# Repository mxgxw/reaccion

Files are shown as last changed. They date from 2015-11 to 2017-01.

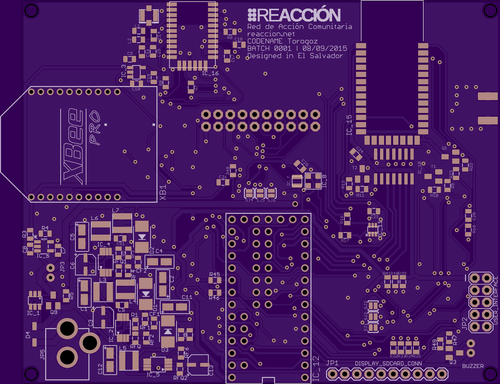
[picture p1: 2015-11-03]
dsn/main/Renders/Reaccion-00-BoardTop.png

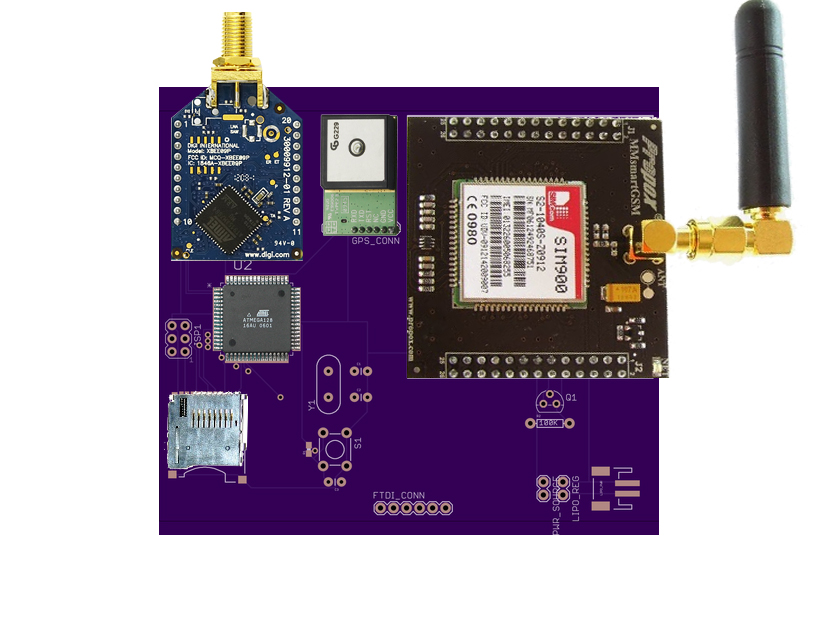
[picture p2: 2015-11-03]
extra/Graficos/Board-pre-render.jpg

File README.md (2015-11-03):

Red de Acción Comunitaria (Reaccion.net)
========================================

"Reaccion.net es una Red de Acción Comunitaria que hace uso de un
dispositivo electrónico que facilita la comunicación y coordinación
de comunidades en caso de siniestros, canalizando eficazmente la
información de alerta temprana y necesidades básicas durante
y después de una emergencia..."

El dispositivo consiste en un módulo de transmisión de datos
inalámbrico diseñado específicamente para enviar mensajes
pre-acordados en la forma de mensajes cortos tipo "semáforo"
indicando distintos niveles de alerta o impácto en una comunidad.
Los dispositivos almacenan y actualizan la información entre si al
estilo de una red P2P de tal manera que la información se guarda
de manera distribuida en toda la red.

En este proyecto de GitHub encontrarás las notas de diseño,
diagramas eléctricos, diseños de las tabletas de circuito impreso,
hojas técnicas y el sofware necesario para controlar el kit Reaccion.net.

Puedes apoyar este proyecto haciendo un "Fork" del mismo, agregando
mejoras al diseño y/o funcionamiento e incorporándolas de nuevo a
través de un "pull request".

Ayúdanos a materializar esta idea a través de SocialLab iniciado
sesión con Faceebok y haciendo click a "Vota por esta idea":

http://www.socialab.com/ideas/ver/15704

Para más información contactanos a través de nuestro
email: info _arroba_ reaccion *punto* net.

Últimas adiciones
=================

+Agregadas las hojas técnicas de los componentes bajo extra/Datasheets.

Costo/Lista de Materiales
=========================

Encuentra la lista de materiales en el archivo bom.csv

Pre-requisitos/Requerimientos
=============================

Pendiente diseño del módulo de cargador/regulador de voltaje LiPO.

Construcción y uso
==================

// TO DO

Carpetas
========

```
raíz
 |--dsn: Archivos de diseño
 |   |--main: Esquemáticos y diagrama de PCB para Eagle.
 |   |--auxiliar: Esquemático y diagrama de PCB en formato PDF imprimible.
 |--doc: Archivos de documentación para construcción y uso.
 |--src: Código fuente del software de control (Arduino).
 |--extra: Anexos
     |--Datasheets: Hojas técnicas de los componentes utilizados.
     |--Gráficos: Renders y bocetos del diseño.
     |--sketchs: Esquemas a mano rápidamente.
```

Excepción de responsabilidades
==============================

> El presente proyecto se comparte "tal cual" con el único objetivo de que sea útil.
El/los creadores del presente hardware y su software asociado no pueden garantizar su
correcto funcionamiento bajo ninguna circunstancia. El/Los autor/es de este proyecto
no podrá/n hacerse responsable/s de cualquier pérdida de carácter material, personal o
económico a su persona o terceros derivados de la utilización del mismo. Este diseño
utiliza componentes emisores de radiofrecuencia que podrían requerir algún tipo de
licenciamiento o pruebas de emisiones antes de su puesta en funcionamiento, asegurate
de estar al tanto de las regulaciones locales respecto al tema.

Licenciamiento
==============
El código fuente del software utilizado en este proyecto está protegido bajo la
licencia GNU/GPL v2.0.

Los archivos de diseño principales y auxiliares están liberados bajo la licencia
CC-BY-SA 3.0 ( https://creativecommons.org/licenses/by-sa/3.0/ ).

> La plantilla de este README.md ha sido desarrollada por la comunidad openhardware.sv
con el objetivo de facilitar la documentación de proyectos. Esta plantilla está protegida
bajo la licencia CC BY, puedes modificarla y redistribuirla manteniendo esta nota de
atribución del autor.

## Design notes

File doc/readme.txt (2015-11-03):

Carpeta de documentación
========================

Esta carpeta contiene todos los archivos de documentación para
el proyecto 72 Horas.

Archivos:

* index.html: Página principal de la documentación en formato HTML.

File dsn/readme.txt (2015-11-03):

Archivos de diseño
==================

Encuentra en esta carpeta los archivos de diagramas eléctricos para el
armado del módulo de tranmisión de datos.

Archivos de diseño principal:

* main\Enlaza.sch : Archivo fuente del diagráma eléctrico para Eagle.
* main\Enlaza.brd : Archivo fuente de la tableta impresa para Eagle.

Archivos de diseño auxiliar:
* auxiliar\Enlaza.pdf : PDF para impresión del diagrama eléctrico.

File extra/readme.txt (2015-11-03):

Archivos extra
==============

Sketchs:

Contiene todos los dibujos a mano hechos para ilustrar el funcionamiento/apariencia/diseño del proyecto.

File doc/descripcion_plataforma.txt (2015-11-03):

Introducción
============

Este documento pretende servir como una guía para explicar el
las razones detrás de la tecnología utilizada en Reacción.net.

Antes de revisar o modificar el diseño es recomendable leer
esta guía para tener una visión más clara de las limitaciones
de conectividad y uso que podría tener la plataforma en una
situación real de implementación.

El escenario
============

Al momento de ocurrir una emergencia, los redes de comunicaciones
son usualmente las primeras afectadas ya sea porque han sido
dañadas o destruidas por el evento o por saturación de las mismas
por los propios usuarios.

Para el caso de El Salvador las redes de comunicaciones de datos
usualmente solo están disponibles en las áreas más urbanizadas,
si bien existe una extensa red móvil de comunicaciones las últimas
estadísticas apuntan a casi 3 dispositivos móviles por habitante,
en una emergencia lo primero que las personas suelen hacer es
intentar comunicarse con su familia o personas cercanas saturando
la red de comunicaciones móviles.

En los últimos años las soluciones basadas en "la nube" se han
vuelto muy de moda, a pesar de tener excepcionales características
en capacidad de procesamiento y disponibilidad, para ser usables
requieren de una infraestructura de comunicaciones funcional,
haciendolas poco viables al momento de una emergencia a menos que
se invierta previamente en la creación de una infraestructura
muy resiliente a los desastres.

Diseño no intrusivo
===================

En una emergencia, la prioridad de las personas es primero velar
por su propia seguridad. Y luego, una vez esto se ha logrado, en
la medida de lo posible deberían ayudar a otras
personas que necesitan auxilio.

La primera respuesta nunca viene de un equipo especializado de
rescate, ni del gobierno, ni de un organismo internacional. La
primera respuesta es la propia gente en el lugar que ha ocurrido
un desastre dando palabras de aliento y ayudando a mantener la
calma a las personas afectadas en tanto llega la ayuda.

Por ello, cualquier diseño de un dispositivo para emergencias
debe de ser en la medida de lo posible no intrusivo permitiendo
a la gente concentrarse en la emergencia y no en el aparato.

Las vidas se salvan antes, no después
=====================================

El secreto está en la prevención, la alerta temprana y en la
organización de las comunidades. Si esto no existe se cae en
el error de ser reaccionarios y actuar luego de una catástrofe
donde ya poco o nada puede hacerse.

Mensajes cortos, simples, claros y fáciles de entender
======================================================

En emergencias, vale más un mensaje corto con un significado
bien definido que miles de mensajes con información vaga y poco
precisa. Sin embargo la combinación de ambos también puede dar
lugar a una gran cantidad de información valiosa en emergencias.

Reacción.net se centra en el primer tipo de mensajes y para ello
fundamenta su metodo de operación en los planes de emergencia
comunitarios.

Así por ejemplo, una comunidad podría acordar que "naranja"
indica en el plan de emergencia que el evento ha afectado más
de la mitad de la población.

De esta manera un "color" se vuelve un mensaje claro, previamente
acordado que acarrea una gran cantidad de información. No pretende
en ningún momento ser preciso, pero nos da una idea más clara
de la situación y es más rápido que intentar obtener un detalle
preciso luego de la emergencia.

Pensamos que el detalle es tarea de las Evaluaciones de Daños,
mientras tanto la pregunta es ¿A donde focalizar las evaluaciones?
¿Quienes podrían necesitar ayuda inmediata? ¿A donde comenzar a
intervenir? El equipo pretende ayudar a responder estas preguntas
en las primeras horas luego de ocurrido un evento.

Pérdida de la memoria
=====================

En una emergencia, uno de los problemas más graves es la pérdida
de la memoria de lo ocurrido. En un desastre de grandes proporciones
es necesario que los investigadores realizen un trabajo forense
para tratar de determinar qué fué lo que sucedio.

Reacción.net provee de un registro distribuido de eventos, de tal
manera que todos los nodos guardan información de la situación
de la red.

De esta manera aunque se perdieran todos los nodos menos uno, sería
posible regresar en el tiempo y conocer qué fué lo que ocurrió como
ocurre en las cajas negras de los aviones.

Adicionalmente el sistema está diseñado de tal manera que se pueda
sincronizar automáticamente al momento de conectarse a la red, de
tal manera que todos los nodos pueden conocer la información de los
demás.

Consideraciones técnicas
========================

Tomando en cuenta todo lo anterior, es posible definir los
parámetros de funcionamiento básico que deberá poseer el
dispositivo:

   1 - El dispositivo debe basar su funcionamiento en la interacción
       con la gente, no algo por encima de o que reemplace a la gente.
   2 - El canal de transmisión de datos no debe de ser centralizado
       y/o depender de infraestructura existente.
   3 - El canal de transmisión de datos secundario puede depender
       de infraestructura existente pero no debe de ser un requerimiento
       para el funcionamiento del dispositivo.
   4 - Cada nodo debe poseer medios para conocer su ubicación.
   5 - Cada nodo debe poseer un registro de los eventos de la red
       a la que se encuentra asociado.
   6 - La interfaz debe ser minimalista, orientada a una función 
       específica y no-intrusiva.
   7 - Infraestructura libre, replicable y adaptable por los usuarios, 
       siguiendo la filosofía del Hardware de Fuentes Abiertas.

En base a lo anterior se ha elegido la siguiente tecnología para
su funcionamiento:

1 - Basado en la gente: Si bien este no es un requerimiento técnico, el
equipo se basa en los planes de emergencia existentes, cada función del
aparto esta asociada a una acción determinada por el plan de emergencia
comunitario. No hay un mensaje "estándar" sino un mutuo acuerdo entre
las comunidades participantes y una organización previa.

2 - Canal primario:

Para proveer de conectividad  se han elegido los módulos de transmisión
de datos inalambricos de tipo espectro ensanchado XBee DIGIMESH 900HP,
estos transmisores son capaces de establecer redes malladas totalmente
descentralizadas y proveen rangos de transmisión aceptables (entre
660m y 6Km). Estos módulos se encargan de manejar todo el protocolo
de transmisión a bajo nivel permitiendo al diseñador centrarse en las
funciones de la aplicación específica más que en los detalles de la capa
de red de comunicaciones. La desventaja de estos módulos es que trabajan
con un ancho de banda muy limitado (entre 10Kbps y 200Kbps) en una banda
de transmisión de datos regulada en la mayor parte del mundo.

Partiendo de que el sistema se basa en la transmisión de datos simples,
previamente acordados el ancho de banda no debería representar mayor 
problema. Respecto al licenciamiento de los equipos creemos posible
que para el tipo de aplicación que se desea implementar se pueden obtener
las autorizaciones o licenciamientos correspondientes según
sea el caso.

3 - Canal secundario:

Se ha elegido el módulo de tranmisión de datos sobre la red GSM GPRS
PROPOX MMsmartGSM por su bajo costo y por estar basado en el chip SIM900,
este chip posee una hoja de especificaciones fácilmente accesible y
provee de la funcionalidad de "celular en un chip". Adicionalmente
cuenta con un stack TCP/IP integrado accesible desde sencillos comandos
AT vía Serial por lo que "descarga" el trabajo de establecimiento de
conexión y envio de datos al miscroprocesador principal el kit Reaccion.net.

Sin embargo, no pensamos que un canal secundario GSM GPRS sea la solución
final a todo. En futuras versiones se podría intercambiar por un módulo
WiFI o alguna solución de acceso a internét móvil como WiMAX o similares.

4 - Medios de ubicación:

Se ha elegido el módulo SkyLab SKM53, este es un módulo GSM con antena
cerámica integrada y salida de comunicaciones serial. La salida es
estándar NMEA y es de bajo muy coste.

5 - Almacenamiento:

El módulo implementa un protocolo que permite el sincronizado remoto, se
da prioridad al nodo con el mensaje más nuevo y los nodos con información
más antigua se intentan actualizar solicitando los datos al nodo con
información más reciente.

Para el almacenamiento interno se han elegido memorias del tipo SD, el
protocolo debería garantizar también la integridad de los datos y proveer
algún medio de recuperación, se espera que la estructura P2P ayude a cum
plir con este cometido.

6 - Interfaz de usuario:

Un pequeño display LCD, un buzzer de alarma sonora y un teclado de 9 teclas
compondrán la interfaz de usuario. Se utilizará un micro-controlador por
separado para administrar la interfaz de usuario y el despliegue de mensajes.

7 - Infraestructura libre y replicable:

Se ha decidido utilizar dos microcontroladores Amtel AVR por el motivo de
hacerlo compatible con la plataforma Arduino y fomentar el mejoramiento
y adaptación de la plataforma a las necesidades locales.

Los procesadores AVR son también de bajo costo, si bien su funcionalidad
puede resultar limitada, gracias a la plataforma Arduino son ampliamente
disponibles a muy bajo costo.

El sistema posee dos microcontroladores, un ATmega1280 que se encargará
de mantener los protocolos de comunicaciones. Se ha elegido este
microcontrolador por poseer 4 puertos USART por hardware, la idea de
utilizar USART es que la implementación será fácilmente adaptable que
utilizando un bus inter-chip, aunque no es una regla estricta. Es muy
posible que en futuras versiones de reaccion.net con un microcontrolador
de mayor capacidad de procesamiento sea mucho más factible utilizar un
bus de comuncación inter-chip como I2C o SPI.

El Segundo microcontrolador se encargará de manejar la interfaz de usuario,
una de las principales razones para elegir este modo de trabajo era para
"aislar" por completo los bloques funcionales, así un bug en la interfaz
de usuario no debería afectar el módulo de comunicaciones y viceversa.

Además esto permitirá mejorar la interfaz de usuario sin necesidad de
modificar el protocolo de comunicación de red.

Fuente de alimentación y consumo
================================

El sistema cuenta con un cargador/nivelador de voltaje que trabajará a
3.3V para los ATmega, el XBee y el GPS y conectará el módulo GSM
directamente a la batería del tipo Ión-Litio/Polímero.

Se espera que el sistema se encuentre en modo de escucha la mayor parte
del tiempo, esto con el objetivo de aumentar la autonomía con baterías.

Para el prototipo incial se espera que se pueda tener una autonomía
de unas 12 horas aunque se espera que para la versión final se pueda
cubrir el rango completo de las 72 horas luego de una emergencia.

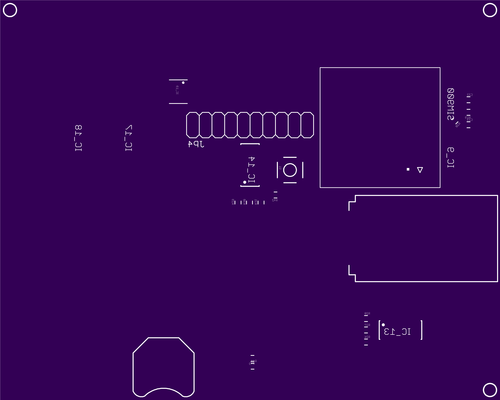
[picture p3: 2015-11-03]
dsn/main/Renders/Reaccion-04-BottomSilkScreen.png

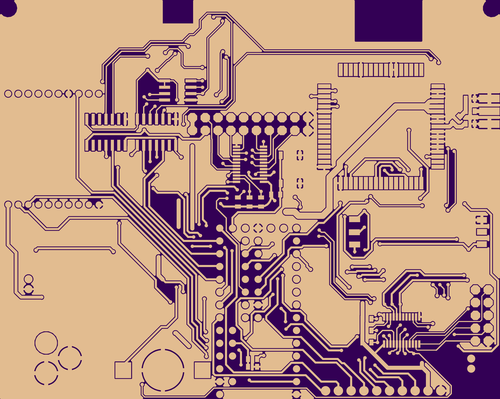
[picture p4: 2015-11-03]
dsn/main/Renders/Reaccion-04-BottomLayer.png

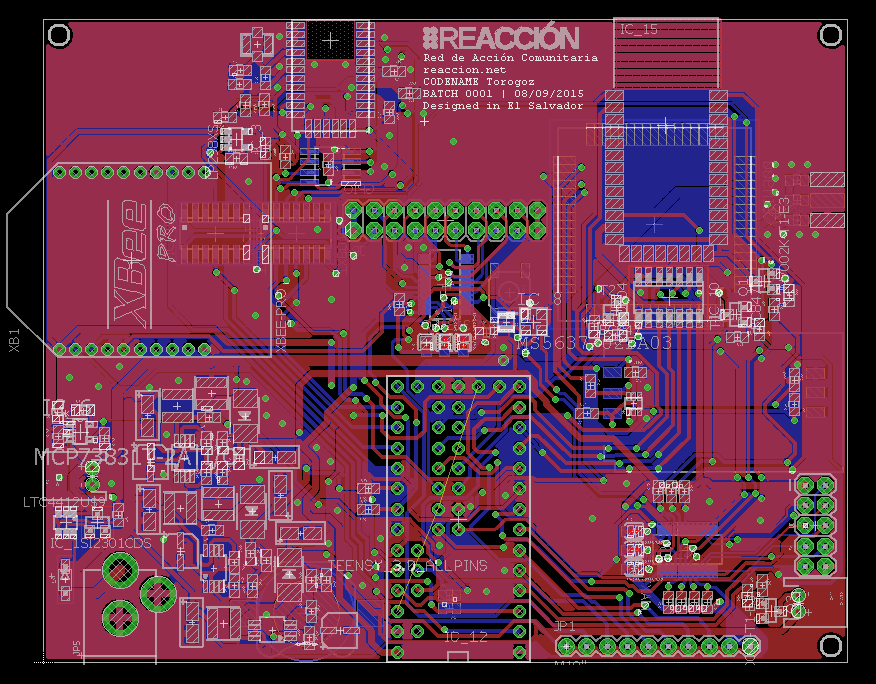
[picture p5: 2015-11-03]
dsn/main/Renders/EAGLE-PCB.png

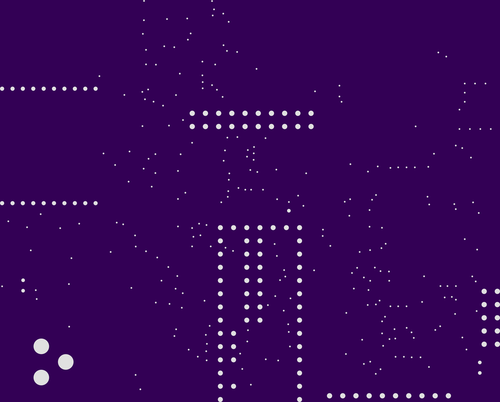
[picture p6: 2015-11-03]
dsn/main/Renders/Reaccion-02-Drills.png

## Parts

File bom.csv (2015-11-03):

# de parte del proveedor | Nombre | Descripción | Proveedor | Cantidad | Unidad medida | Precio Unitario | Total
PRT-0001 | ATmega328 with Arduino Optiboot (Uno) | Microcontrolador con bootloader pre-grabado para compatibilidad con Arduino. | SparkFun | 1 | Unidad | - | #VALOR!
MmsmartGSM | PROPOX MmsmartGSM | Módulo Módem GSM cuadribanda. | PROPOX | 1 | Unidad | - | #VALOR!
602-1349-ND | XBEE PRO S3B 900HP RPSMA | Módulo de transmisión inalambrica para redes tipo MESH. | DigiKey | 1 | Unidad | - | #VALOR!
PRT-11231 | Power Cell - LiPo Charger/Booster | Módulo para carga/nivelación de voltaje para baterías Ion Litio. | SparkFun | 1 | Unidad | - | #VALOR!
PRT-08483 | Polymer Lithium Ion Battery - 2000mAh | Batería de Ion Litio 2000mAh | SparkFun | 1 | Unidad | - | #VALOR!
COM-00538 | Crystal 8MHz | Cristal PiezoElectrico de 8MHz | SparkFun | 1 | Unidad | - | #VALOR!
COM-08571 | Capacitor Ceramic 22pF | Capacitor cerámico de 22pF | SparkFun | 2 | Unidad | - | #VALOR!
COM-08375 | Capacitor Ceramic 0.1uF | Capacitor cerámico de 0.1uF | SparkFun | 1 | Unidad | - | #VALOR!
COM-00097 | Mini Push Button Switch | Botón Pulsador | SparkFun | 1 | Unidad | - | #VALOR!

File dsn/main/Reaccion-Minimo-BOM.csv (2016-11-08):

Qty | Value | Device | Package | Parts | Description | PROD_ID | VALUE
1 |  | DIODESMB | SMB-DIODE | D1 | Diode | DIO-09646
3 |  | DIODESOD123 | SOD-123 | D2, D3, D7 | Diode
2 |  | M04PTH | 1X04 | RX_MOD_CONN, TX_MOD_CONN | Header 4
2 |  | TRANSISTOR_NPNSOT23-3 | SOT23-3 | Q1, Q2 | Generic NPN BJT | TRANS-08049
1 | 0 | RESISTOR0805-RES | 0805 | R5 | Resistor
1 | 0.1uF | CAP0805 | 0805 | C4 | Capacitor
1 | 100uF | CPOL-USB/3528-21R | T/3528-12R | C6 | POLARIZED CAPACITOR, American symbol
1 | 100uF | CPOL-USC/6032-28R | C/6032-28R | C5 | POLARIZED CAPACITOR, American symbol
1 | 10K | RESISTOR0805-RES | 0805 | R1 | Resistor
1 | 150 | RESISTOR0805-RES | 0805 | R2 | Resistor
1 | 16MHz | CRYSTAL5X3 | CRYSTAL-SMD-5X3 | Y1 | Various standard crystals. Proven footprints. | XTAL-08218
2 | 18pF | CAP0805 | 0805 | C1, C2 | Capacitor
3 | 1uF | CAP0805 | 0805 | C3, C7, C9 | Capacitor
1 | 2K2 | RESISTOR0805-RES | 0805 | R9 | Resistor
1 | 2X6 FEMALE | M06X2PTH_FEMALE | 2X6 | JP2 |  | CONN-12423 | 2X6 FEMALE
2 | 330 | RESISTOR0805-RES | 0805 | R3, R4 | Resistor
2 | 4.7K | RESISTOR0805-RES | 0805 | R6, R8 | Resistor
1 | 4.7uF | CAP0805 | 0805 | C8 | Capacitor
1 | 6K8 | RESISTOR0805-RES | 0805 | R7 | Resistor
1 | ATMEGA328P_TQFP | ATMEGA328P_TQFP | TQFP32-08 | U1 |  | IC-09069 | ATMEGA328P_TQFP
1 | AVRISP-6 | AVRISP-6 | AVRISP | ISP1 | AVR ISP HEADER
1 | BUZZERPTH | BUZZERPTH | BUZZER-12MM | SG1 | Buzzer 12mm
1 | FTDI_BASICPTH | FTDI_BASICPTH | FTDI_BASIC | JP3 | FTDI Basic header with labels
1 | LCD-HD447803-HOLES16X2-3-HOLES | LCD-HD447803-HOLES16X2-3-HOLES | LCD-16X2-3HOLES | LCD
1 | MIC5219 5V | V_REG_MIC52195V | SOT23-5 | U2 | V_REG MIC5219 | VREG-10107 | MIC5219 5V
1 | POWER_JACKPTH | POWER_JACKPTH | POWER_JACK_PTH | JP6 | Power Jack | CONN-08197
2 | RED | LED-RED1206 | LED-1206 | D5, D6 | Assorted Red LEDs | DIO-09912 | RED
5 | SWITCH-MOMENTARY-2SMD | SWITCH-MOMENTARY-2SMD | TACTILE-SWITCH-SMD | RESET, S1, S2, S3, S4 | Various NO switches- pushbuttons, reed, etc | SWCH-08247
1 | TC33 | TC33 | TC33 | U$2
1 | WS2811 | LED-TRICOLOR-5050-ICWS2811 | LED-TRICOLOR-5050-IC | U3 | WS2812 RGB LED w/ WS2811 driver | DIO-11598 | WS2811

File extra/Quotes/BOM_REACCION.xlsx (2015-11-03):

CANTIDAD | FUNCION | SUB-FUNCION | P/N | NOMBRE | COSTO | TOTAL
1 | POWER | BATT | N/D | LIPO BATT 2500mAH | $15.75 | $15.75
1 | POWER | EXTERNAL POWER | N/D | Medium 6V 2W solar panel | $47.19 | $47.19
1 | POWER | SDCARD | LM2621MM/NOPB | IC REG MULTI CONFIG ADJ 8VSSOP | $2.81 | $2.81
2 | POWER | BATT CHARGER 5V RAIL | NR4018T6R8M | FIXED IND 6.8UH 1.06A 132 MOHM | $0.48 | $0.96
1 | POWER | BATT CHARGER 5V RAIL | 08055C104KAT2A | CAP CER 0.1UF 50V 10% X7R 0805 | $0.15 | $0.15
1 | POWER | BATT CHARGER 5V RAIL | F950J336MPAAQ2 | CAP TANT 33UF 6.3V 20% 0805 | $1.41 | $1.41
1 | POWER | BATT CHARGER 5V RAIL | F921C684MPA | CAP TANT 0.68UF 16V 20% 0805 | $0.52 | $0.52
1 | POWER | BATT CHARGER 5V RAIL | C0402C330J3GACTU | CAP CER 33PF 25V 5% NP0 0402 | $0.51 | $0.51
1 | POWER | BATT CHARGER 5V RAIL | MBRS140T3G | DIODE SCHOTTKY 40V 1A SMB | $0.85 | $0.85
4 | POWER | BATT CHARGER 5V RAIL | N/D | RESISTOR 0805 | $0.15 | $0.60
1 | POWER | BATT CHARGER | MCP73811T-420I/OT | IC LI-ION/LI-POLY CTRLR SOT23-5 | $0.92 | $0.92
2 | POWER | BATT CHARGER | N/D | RESISTOR 0805 | $0.15 | $0.30
2 | POWER | BATT CHARGER | N/D | CAP CER 4.7UF X7R 0805 | $0.15 | $0.30
1 | POWER | BATT CHARGER | LTST-C191KGKT | LED GREEN CLEAR THIN 0603 SMD | $0.45 | $0.45
1 | POWER | POWERPATH CONTROLLER | LTC4412IS6#TRMPBF | IC OR CTRLR SRC SELECT TSOT23-6 | $5.15 | $5.15
1 | POWER | POWERPATH CONTROLLER | FDN306P | MOSFET P-CH 12V 2.6A SSOT3 | $0.87 | $0.87
1 | POWER | POWERPATH CONTROLLER | 1N5819HW-7-F | DIODE SCHOTTKY 40V 1A SOD123 | $0.78 | $0.78
1 | POWER | POWERPATH CONTROLLER | N/D | RESISTOR 0805 | $0.15 | $0.15
1 | POWER | 3V3 RAIL | LM2621MM/NOPB | IC REG MULTI CONFIG ADJ 8VSSOP | $2.81 | $2.81
2 | POWER | 3V3 RAIL | NR4018T6R8M | FIXED IND 6.8UH 1.06A 132 MOHM | $0.48 | $0.96
1 | POWER | 3V3 RAIL | 08055C104KAT2A | CAP CER 0.1UF 50V 10% X7R 0805 | $0.15 | $0.15
1 | POWER | 3V3 RAIL | F950J336MPAAQ2 | CAP TANT 33UF 6.3V 20% 0805 | $1.41 | $1.41
1 | POWER | 3V3 RAIL | F921C684MPA | CAP TANT 0.68UF 16V 20% 0805 | $0.52 | $0.52
1 | POWER | 3V3 RAIL | C0402C330J3GACTU | CAP CER 33PF 25V 5% NP0 0402 | $0.51 | $0.51
1 | POWER | 3V3 RAIL | MBRS140T3G | DIODE SCHOTTKY 40V 1A SMB | $0.85 | $0.85
4 | POWER | 3V3 RAIL | N/D | RESISTOR 0805 | $0.15 | $0.60
1 | POWER | 12V RAIL | LM2621MM/NOPB | IC REG MULTI CONFIG ADJ 8VSSOP | $2.81 | $2.81
1 | POWER | 12V RAIL | NR4018T6R8M | FIXED IND 6.8UH 1.06A 132 MOHM | $0.48 | $0.48
1 | POWER | 12V RAIL | F950J336MPAAQ2 | CAP TANT 33UF 6.3V 20% 0805 | $1.41 | $1.41
1 | POWER | 12V RAIL | F921C684MPA | CAP TANT 0.68UF 16V 20% 0805 | $0.52 | $0.52
1 | POWER | 12V RAIL | C0402C330J3GACTU | CAP CER 33PF 25V 5% NP0 0402 | $0.51 | $0.51
1 | POWER | 12V RAIL | MBRS140T3G | DIODE SCHOTTKY 40V 1A SMB | $0.85 | $0.85
4 | POWER | 12V RAIL | N/D | RESISTOR 0805 | $0.15 | $0.60
1 | POWER | 1V8 RAIL | TC1015-1.8VCT713 | IC REG LDO 1.8V 0.1A SOT23-5 | $0.61 | $0.61
1 | POWER | 1V8 RAIL | N/D | CAPACITOR GEN | $0.75 | $0.75
1 | DEVICES | GPS | M10478-A1 | GPS ANTENNOVA | $29.28 | $29.28
6 | DEVICES | GPS | N/D | CAPACITOR GEN | $0.75 | $4.50
3 | DEVICES | GPS | N/D | RESISTOR 0805 | $0.15 | $0.45
1 | DEVICES | GPS | SST25WF040B-40I/SN | IC FLASH 4MB 40MHZ SPI 8SOIC | $1.42 | $1.42
1 | DEVICES | GPS | TXB0104D | IC VOLT-LEVEL TRANSLATOR 14-SOIC | $2.62 | $2.62
1 | DEVICES | GSM/GPRS | SIM900 | QUAD BAND GSM/GPRS MODEM | $21.75 | $21.75
3 | DEVICES | GSM/GPRS | BC847 | TRANSISTOR/GENERIC | $0.32 | $0.95
10 | DEVICES | GSM/GPRS | N/D | RESISTOR 0805 | $0.15 | $1.50
3 | DEVICES | GSM/GPRS | N/D | CAPACITOR GEN | $0.75 | $2.25
1 | DEVICES | GSM/GPRS | SMF05C.TCT | TVS DIODE 5VWM 12.5VC SC70-6 | $1.26 | $1.26
1 | DEVICES | GSM/GPRS | 9162006301150 | CONN SIM CARD HINGED TYPE R/A | $1.97 | $1.97
1 | DEVICES | GSM/GPRS | TXB0104D | IC VOLT-LEVEL TRANSLATOR 14-SOIC | $2.62 | $2.62
1 | DEVICES | DISPLAY | PID-1480 | 2.2'' DISPLAY | $26.25 | $26.25
1 | DEVICES | SDCARD | DM3CS-SF | CONN MICRO SD CARD HINGED TYPE | $2.49 | $2.49
2 | DEVICES | SDCARD | SMF05C.TCT | TVS DIODE 5VWM 12.5VC SC70-6 | $1.26 | $2.52
1 | DEVICES | XBEE | XBP9B-DMST-012 | XBEE PRO DIGMESH S3B 900HP RPSMA | $58.50 | $58.50
1 | DEVICES | XBEE | 0600-00028 | ANTENNA 915MHZ 1/2WV 6" RA RPSMA | $21.00 | $21.00
1 | DEVICES | UI | SMF05C.TCT | TVS DIODE 5VWM 12.5VC SC70-6 | $1.26 | $1.26
4 | DEVICES | UI | N/D | WATERPROOF METAL BUTTON | $5.25 | $21.00
1 | DEVICES | UI | N/D | ANALOG THUMB JOYSTICK | $3.68 | $3.68
1 | DEVICES | UI | MAS800SQ | BUZ PIEZO 12V CIRC 26.3MM RADIAL | $11.01 | $11.01
1 | CORE | CORE | MK60FN1M0VLQ12 | IC MCU ARM 1MB FLASH 144LQFP | $20.05 | $20.05
1 | CORE | USB | 10118194-0001LF | Connector Receptacle USB - micro B 2.0 5 Position Surface Mount, Right Angle, Horizontal | $0.69 | $0.69
1 | DEVICES | GSM/GPRS | N/D | CAPACITOR GEN | $0.75 | $0.75
1 | MANUF | MANUF | N/D | EXPRESS PCB FAB | $11.38 | $11.38
1 | MANUF | MANUF | N/D | ASSEMBLY | $99.75 | $99.75
GRAN TOTAL |  |  |  |  |  | $446.94

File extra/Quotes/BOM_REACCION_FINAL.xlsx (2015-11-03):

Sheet: KIT REACCION
CANTIDAD | FUNCION | SUB-FUNCION | P/N | NOMBRE
1 | POWER | BATT | N/D | LIPO BATT 2500mAH
1 | POWER | EXTERNAL POWER | N/D | Medium 6V 2W solar panel
1 | POWER | BATT CHARGER 5V RAIL | LM2621MM/NOPB | IC REG MULTI CONFIG ADJ 8VSSOP
2 | POWER | BATT CHARGER 5V RAIL | NR4018T6R8M | FIXED IND 6.8UH 1.06A 132 MOHM
1 | POWER | BATT CHARGER 5V RAIL | 08055C104KAT2A | CAP CER 0.1UF 50V 10% X7R 0805
1 | POWER | BATT CHARGER 5V RAIL | F950J336MPAAQ2 | CAP TANT 33UF 6.3V 20% 0805
1 | POWER | BATT CHARGER 5V RAIL | F921C684MPA | CAP TANT 0.68UF 16V 20% 0805
1 | POWER | BATT CHARGER 5V RAIL | C0402C330J3GACTU | CAP CER 33PF 25V 5% NP0 0402
1 | POWER | BATT CHARGER 5V RAIL | MBRS140T3G | DIODE SCHOTTKY 40V 1A SMB
4 | POWER | BATT CHARGER 5V RAIL | N/D | RESISTOR 0805
1 | POWER | BATT CHARGER | MCP73811T-420I/OT | IC LI-ION/LI-POLY CTRLR SOT23-5
2 | POWER | BATT CHARGER | N/D | RESISTOR 0805
2 | POWER | BATT CHARGER | N/D | CAP CER 4.7UF X7R 0805
1 | POWER | BATT CHARGER | LTST-C191KGKT | LED GREEN CLEAR THIN 0603 SMD
1 | POWER | POWERPATH CONTROLLER | LTC4412IS6#TRMPBF | IC OR CTRLR SRC SELECT TSOT23-6
1 | POWER | POWERPATH CONTROLLER | FDN306P | MOSFET P-CH 12V 2.6A SSOT3
1 | POWER | POWERPATH CONTROLLER | 1N5819HW-7-F | DIODE SCHOTTKY 40V 1A SOD123
1 | POWER | POWERPATH CONTROLLER | N/D | RESISTOR 0805
1 | POWER | 3V3 RAIL | LM2621MM/NOPB | IC REG MULTI CONFIG ADJ 8VSSOP
2 | POWER | 3V3 RAIL | NR4018T6R8M | FIXED IND 6.8UH 1.06A 132 MOHM
1 | POWER | 3V3 RAIL | 08055C104KAT2A | CAP CER 0.1UF 50V 10% X7R 0805
1 | POWER | 3V3 RAIL | F950J336MPAAQ2 | CAP TANT 33UF 6.3V 20% 0805
1 | POWER | 3V3 RAIL | F921C684MPA | CAP TANT 0.68UF 16V 20% 0805
1 | POWER | 3V3 RAIL | C0402C330J3GACTU | CAP CER 33PF 25V 5% NP0 0402
1 | POWER | 3V3 RAIL | MBRS140T3G | DIODE SCHOTTKY 40V 1A SMB
4 | POWER | 3V3 RAIL | N/D | RESISTOR 0805
1 | POWER | 12V RAIL | LM2621MM/NOPB | IC REG MULTI CONFIG ADJ 8VSSOP
1 | POWER | 12V RAIL | NR4018T6R8M | FIXED IND 6.8UH 1.06A 132 MOHM
1 | POWER | 12V RAIL | F950J336MPAAQ2 | CAP TANT 33UF 6.3V 20% 0805
1 | POWER | 12V RAIL | F921C684MPA | CAP TANT 0.68UF 16V 20% 0805
1 | POWER | 12V RAIL | C0402C330J3GACTU | CAP CER 33PF 25V 5% NP0 0402
1 | POWER | 12V RAIL | MBRS140T3G | DIODE SCHOTTKY 40V 1A SMB
4 | POWER | 12V RAIL | N/D | RESISTOR 0805
1 | POWER | 1V8 RAIL | TC1015-1.8VCT713 | IC REG LDO 1.8V 0.1A SOT23-5
1 | POWER | 1V8 RAIL | N/D | CAPACITOR GEN
1 | DEVICES | GPS | M10478-A1 | GPS ANTENNOVA
6 | DEVICES | GPS | N/D | CAPACITOR GEN
3 | DEVICES | GPS | N/D | RESISTOR 0805
1 | DEVICES | GPS | SST25WF040B-40I/SN | IC FLASH 4MB 40MHZ SPI 8SOIC
1 | DEVICES | GPS | TXB0104D | IC VOLT-LEVEL TRANSLATOR 14-SOIC
1 | DEVICES | GSM/GPRS | SIM900 | QUAD BAND GSM/GPRS MODEM
3 | DEVICES | GSM/GPRS | BC847 | TRANSISTOR/GENERIC
10 | DEVICES | GSM/GPRS | N/D | RESISTOR 0805
3 | DEVICES | GSM/GPRS | N/D | CAPACITOR GEN
1 | DEVICES | GSM/GPRS | SMF05C.TCT | TVS DIODE 5VWM 12.5VC SC70-6
1 | DEVICES | GSM/GPRS | 9162006301150 | CONN SIM CARD HINGED TYPE R/A
1 | DEVICES | GSM/GPRS | TXB0104D | IC VOLT-LEVEL TRANSLATOR 14-SOIC
1 | DEVICES | DISPLAY | PID-1480 | 2.2'' DISPLAY
1 | DEVICES | SDCARD | DM3CS-SF | CONN MICRO SD CARD HINGED TYPE
2 | DEVICES | SDCARD | SMF05C.TCT | TVS DIODE 5VWM 12.5VC SC70-6
1 | DEVICES | XBEE | XBP9B-DMST-012 | XBEE PRO DIGMESH S3B 900HP RPSMA
1 | DEVICES | XBEE | 0600-00028 | ANTENNA 915MHZ 1/2WV 6" RA RPSMA
1 | DEVICES | UI | SMF05C.TCT | TVS DIODE 5VWM 12.5VC SC70-6
4 | DEVICES | UI | N/D | WATERPROOF METAL BUTTON
1 | DEVICES | UI | N/D | ANALOG THUMB JOYSTICK
1 | DEVICES | UI | MAS800SQ | BUZ PIEZO 12V CIRC 26.3MM RADIAL
1 | CORE | CORE | MK60FN1M0VLQ12 | IC MCU ARM 1MB FLASH 144LQFP
1 | CORE | USB | 10118194-0001LF | Connector Receptacle USB - micro B 2.0 5 Position Surface Mount, Right Angle, Horizontal
1 | DEVICES | GSM/GPRS | N/D | CAPACITOR GEN
1 | MANUF | MANUF | N/D | EXPRESS PCB FAB
1 | MANUF | MANUF | N/D | ASSEMBLY

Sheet: KIT VISOR
CANTIDAD | FUNCION | SUB-FUNCION | NOMBRE
1 | VISOR | VISOR | RASPBERRY PI 2 - MODEL B
1 | VISOR | XBEE | XBEE 900HP
1 | VISOR | XBEE | ANTENNA
1 | VISOR | XBEE BREAKOUT | XBEE BASE
1 | VISOR | VISOR | CASE RASPBERRY PI 2
1 | VISOR | VISOR | FUENTE RASPBERRY PI
1 | VISOR | VISOR | CABLE HDMI
1 | VISOR | VISOR | XBEE 900HP

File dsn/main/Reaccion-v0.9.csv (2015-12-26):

Part | Value | Device | Package | Description | MF | MPN | OC_FARNELL | OC_NEWARK | PACKAGE | PROD_ID | SUPPLIER | VALUE
BAT1 | 3.7V | BATTERY12MM | BATTCON_12MM | Battery Holders |  |  |  |  |  | BATT-08044
BUZZER | BATT | M02-JST-2-PTH-NO_SILK | JST-2-PTH-NS | Standard 2-pin 0.1 header. Use with"
C1 | 0.22uF | CAP0805 | 0805 | Capacitor
C2 | 68pF | CAP0805 | 0805 | Capacitor
C3 | 22uF | CAP0805 | 0805 | Capacitor
C4 | 0.22uF | CAP0805 | 0805 | Capacitor
C5 | 68pF | CAP0805 | 0805 | Capacitor
C6 | 47uF | CAP0805 | 0805 | Capacitor
C7 | 4.7uF | CAP0805 | 0805 | Capacitor
C8 | 4.7uF | CAP0805 | 0805 | Capacitor
C9 | 2.2uF | CAP0805 | 0805 | Capacitor
C10 | 470pF | CAP0805 | 0805 | Capacitor
C11 | 470pF | CAP0805 | 0805 | Capacitor
C14 |  | CAP0805 | 0805 | Capacitor
C15 | 2.2uF | CAP0805 | 0805 | Capacitor
C16 | 2.2uF | CAP0805 | 0805 | Capacitor
C17 | 22pF | CAP0805 | 0805 | Capacitor
C18 | 22pF | CAP0805 | 0805 | Capacitor
C19 | 22pF | CAP0805 | 0805 | Capacitor
C20 | 22pF | CAP0805 | 0805 | Capacitor
C21 | 100nF | CAP0805 | 0805 | Capacitor
C22 |  | CAP0805 | 0805 | Capacitor
C23 |  | CAP0805 | 0805 | Capacitor
C24 | 1uF | CAP0805 | 0805 | Capacitor
C25 | 1uF | CAP0805 | 0805 | Capacitor
C27 | 1uF | CAP0805 | 0805 | Capacitor
C28 | 1uF | CAP0805 | 0805 | Capacitor
CIN | 100uF | TPSB107M010R0400 | 1210-POLARIZED
CIN1 | 100uF | TPSB107M010R0400 | 1210-POLARIZED
D4 | 1N5819HW-7-F | 1N5819HW-7-F | SOD123
DOUT | SD1206S040S2R0 | SD1206S040S2R0 | 1206-POL
DOUT1 | SD1206S040S2R0 | SD1206S040S2R0 | 1206-POL
IC_1 | LTC4412 | LTC4412 | SOT23-6L
IC_3 | LP298XS | LP298XS | SOT23-5L
IC_6 | MCP73831T-2ATI/OT | MCP73831T-2ATI/OT | SOT95P300X145-5N | IC, BATT CHARGER, Li-Ion Li-Polymer, 500 mA |  | MCP73831T-2ATI/OT | 1834890 | 84R5196 | SOT23-5 |  | Microchip
IC_7 | MMA8653FC | MMA8653FC | 2X2-DFN
IC_8 | MS5637-02BA03 | MS5637-02BA03 | MS5637-02BA03
IC_9 | SIM900 | SIM900 | SIM900
IC_10 | TXB0104 | TXB0104 | SO14
IC_11 | SMF05C | SMF05C | SOT665
IC_12 | TEENSY_3.0_ALLPINS | TEENSY_3.0_ALLPINS | TEENSY_3.0_ALLPINS | Teensy 3.0 with all pin holes and optional SMD-mount unshrouded header on bottom of Teensy 3.0. For more basic versions, see 'Basic', '+4' and 'AllAnalogPins'.Requires the installation of a un-shrouded SMD header on the underside of the Teensy 3.0
IC_13 | MAX7313AEG | MAX7313AEG | QSOP24 | 16-Port I/O Expander with LED Intensity Control, Interrupt, and Hot-Insertion Protection |  | MAX7313AEG+ | unknown | 53K7268
IC_15 | HC_05 | HC_05 | BLUETOOTH_SMD | HC-05 Bluetooth Module
IC_16 | M10478 | M10478 | M10478
IC_17 | TXB0104 | TXB0104 | SO14
IC_18 | TXB0104 | TXB0104 | SO14
IC_19 | SST25WF040B | SST25WF040B | SO08
J$1 | SMA_EDGE | SMA_EDGE | SMA-EDGE | SMA Antenna Connector
J1 | U.FL | U.FL | U.FL | SMD antenna connector- WRL-09144
JP1 | M10";M10"" | 1X10 | Header 10
JP2 | UI | PINHD-2X5 | 2X05 | PIN HEADER
JP3 | BATT | M02-JST-2-PTH-NO_SILK | JST-2-PTH-NS | Standard 2-pin 0.1 header. Use with"
JP6 | USB-B | USBPTH | USB-B-PTH | USB Connectors |  |  |  |  |  | CONN-08278 |  | USB-B
L1 |  | INDUCTOR0805 | 0805 | Inductors
L2 |  | INDUCTOR0805 | 0805 | Inductors
L3 | 1.8uH | SRR4028 | SRR4028 | POWER INDUCTOR
L6 | 1.8uH | SRR4028 | SRR4028 | POWER INDUCTOR
Q1 | 2N7002K-T1-E3 | MOSFET-NREFLOW | SOT23 | N-Channel Mosfet
Q3 | 2N7002K-T1-E3 | MOSFET-NREFLOW | SOT23 | N-Channel Mosfet
Q9 | SI2301CDS | SI2301CDS | SOT23
R1 | 10K | RESISTOR0805-RES | 0805 | Resistor
R2 | 10K | RESISTOR0805-RES | 0805 | Resistor
R3 | 10k | RESISTOR0805-RES | 0805 | Resistor
R4 | 2K | RESISTOR0805-RES | 0805 | Resistor
R5 | 10k | RESISTOR0805-RES | 0805 | Resistor
R6 | 10K | RESISTOR0805-RES | 0805 | Resistor
R7 | 10K | RESISTOR0805-RES | 0805 | Resistor
R8 | 10K | RESISTOR0805-RES | 0805 | Resistor
R9 | 10K | RESISTOR0805-RES | 0805 | Resistor
R10 | 10K | RESISTOR0805-RES | 0805 | Resistor
R11 | 10K | RESISTOR0805-RES | 0805 | Resistor
R12 | 10K | RESISTOR0805-RES | 0805 | Resistor
R13 | 30K | RESISTOR0805-RES | 0805 | Resistor
R14 | 10K | RESISTOR0805-RES | 0805 | Resistor
R15 | 84.5K | RESISTOR0805-RES | 0805 | Resistor
R16 | 22 | RESISTOR0805-RES | 0805 | Resistor
R17 | 22 | RESISTOR0805-RES | 0805 | Resistor
R18 | 22 | RESISTOR0805-RES | 0805 | Resistor
R19 | 0 | RESISTOR0805-RES | 0805 | Resistor
R20 | 0 | RESISTOR0805-RES | 0805 | Resistor
R21 | 10K | RESISTOR0805-RES | 0805 | Resistor
R22 | 10K | RESISTOR0805-RES | 0805 | Resistor
R23 | 10K | RESISTOR0805-RES | 0805 | Resistor
R26 | 4.7K | RESISTOR0805-RES | 0805 | Resistor
R27 | 4.7K | RESISTOR0805-RES | 0805 | Resistor
R28 | 4.7K | RESISTOR0805-RES | 0805 | Resistor
R42 | 4.7K | RESISTOR0805-RES | 0805 | Resistor
R43 | 10K | RESISTOR0805-RES | 0805 | Resistor
R44 | 10K | RESISTOR0805-RES | 0805 | Resistor
R45 | 4.7K | RESISTOR0805-RES | 0805 | Resistor
R46 | 4.7K | RESISTOR0805-RES | 0805 | Resistor
R47 | 10K | RESISTOR0805-RES | 0805 | Resistor
R49 | 10K | RESISTOR0805-RES | 0805 | Resistor
S1 | SWITCH-MOMENTARY-2SMD-REDUNDANT | SWITCH-MOMENTARY-2SMD-REDUNDANT | TACTILE-SWITCH-SMD | Various NO switches- pushbuttons, reed, etc |  |  |  |  |  | SWCH-08247
SIMCONN | SIMHOLDER3 | SIMHOLDER3 | SIMHOLDER3 | Alternate SIM card socket
SJ1 | SOLDERJUMPERTRACE | SOLDERJUMPERTRACE | SJ_2S-TRACE | Solder Jumper
SJ2 | SOLDERJUMPERTRACE | SOLDERJUMPERTRACE | SJ_2S-TRACE | Solder Jumper
SJ3 | SOLDERJUMPERTRACE | SOLDERJUMPERTRACE | SJ_2S-TRACE | Solder Jumper
T1 | BC847 | BC847 | SOT23 | NPN TRANSISTOR
T2 | BC847 | BC847 | SOT23 | NPN TRANSISTOR
U$1 | LT1935ES5 | LT1935ES5 | SOT23-5
U$2 | LT1935ES5 | LT1935ES5 | SOT23-5
U1 | MIC5219 3.3V | V_REG_MIC52193.3V | SOT23-5 | V_REG MIC5219 |  |  |  |  |  | VREG-09872 |  | MIC5219 3.3V
XB1 | XBEE-PRO | XBEE-PRO | XBEE-PRO | XBee (TM) /XBee-PRO(TM) OEM RF Modules |  | XBP24-AWI-001 | 1337916 | 42M2667

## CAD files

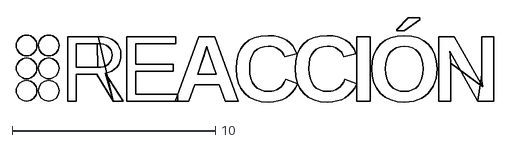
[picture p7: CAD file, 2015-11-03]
extra/Graficos/logo_PCB.dxf
23.5 x 4.14

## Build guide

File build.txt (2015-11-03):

Construyendo mi proyecto
========================

TODO.

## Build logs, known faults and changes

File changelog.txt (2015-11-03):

Versión 0.01
===========================
Publicada: 12/01/14

Cambios:

* Agregados esquematicos e ingresada plantilla OSHW

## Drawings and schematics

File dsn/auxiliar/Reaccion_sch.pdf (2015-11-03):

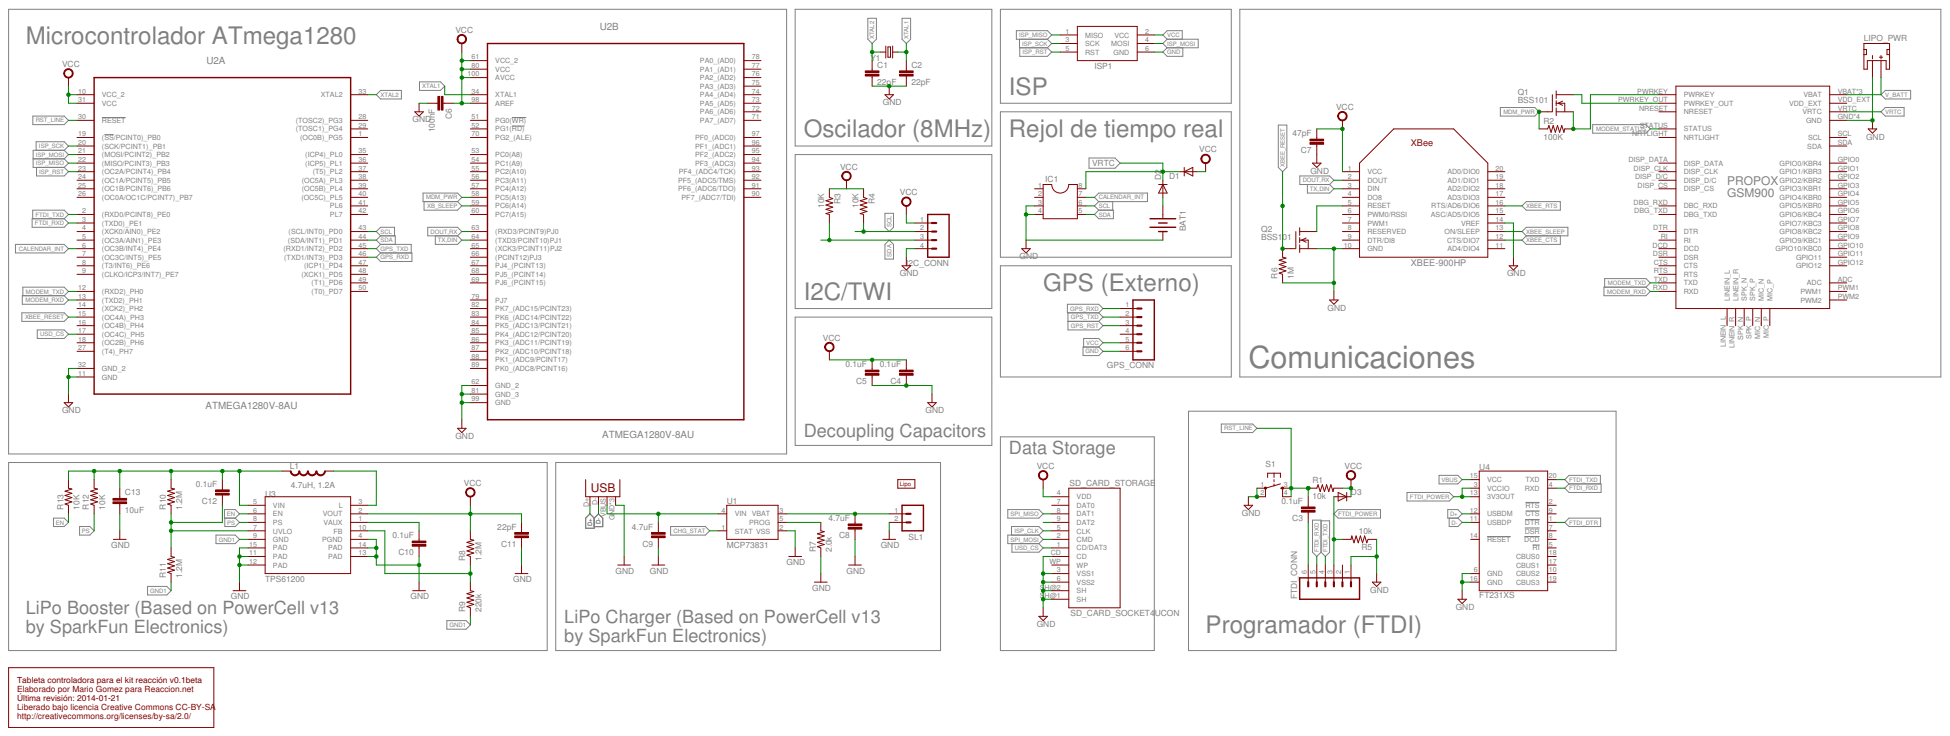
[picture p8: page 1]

LiPo Booster (Based on PowerCell v13
by SparkFun Electronics)

LiPo Charger (Based on PowerCell v13

Tableta controladora para el kit reacción v0.1beta
Elaborado por Mario Gomez para Reaccion.net Última revisión: 2014-01-21

Liberado bajo licencia Creative Commons CC-BY-SA
http://creativecommons.org/licenses/by-sa/2.0/

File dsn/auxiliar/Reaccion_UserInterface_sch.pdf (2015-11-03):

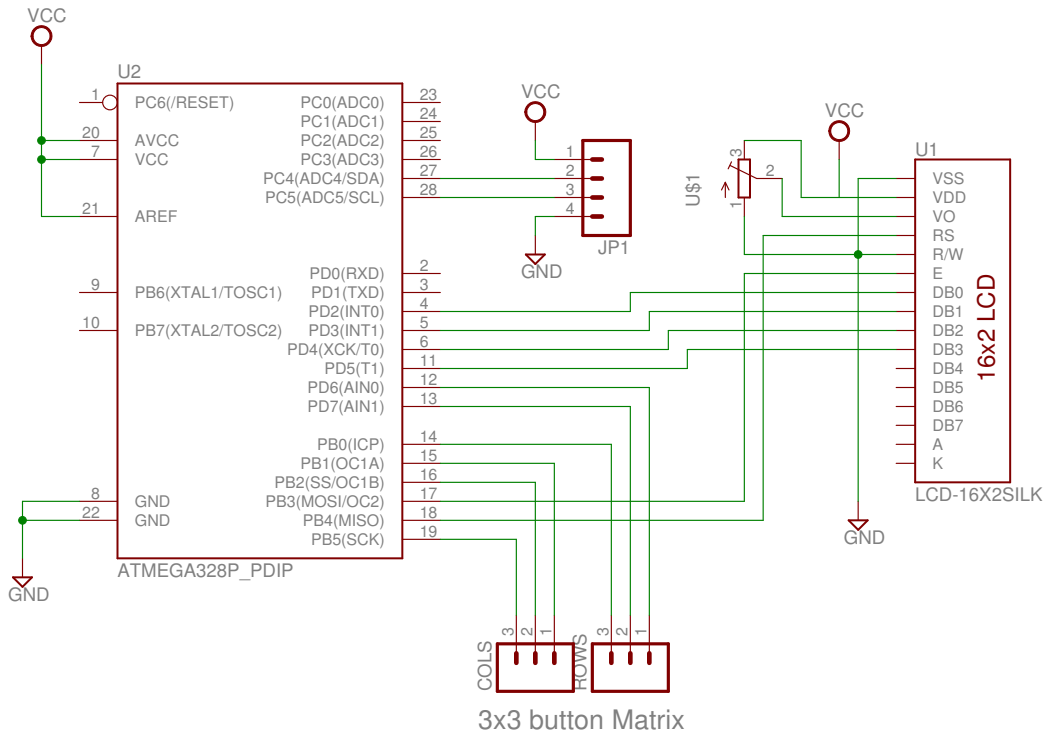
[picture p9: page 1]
3x3 button Matrix; LCD-16X2SILK; ATMEGA328P_PDIP; VCC; GND; VDD VO; VSS; PB5(SCK); PB7(XTAL2/TOSC2) 10; PB6(XTAL1/TOSC1); 8 GND 22; AREF 21; AVCC 20; PB4(MISO); 18 PB3(MOSI/OC2); 15 PB0(ICP); PD7(AIN1); 13 PD6(AIN0); 11 PD4(XCK/T0); 6 PD3(INT1); 5 PD2(INT0); 4 PD1(TXD); 3 PD0(RXD); PC5(ADC5/SCL); 28 PC4(ADC4/SDA); 27 PC3(ADC3); 26 PC2(ADC2); 25 PC1(ADC1); 24 PC0(ADC0); 23 PC6(/RESET); COLS; ROWS; 16x2 LCD

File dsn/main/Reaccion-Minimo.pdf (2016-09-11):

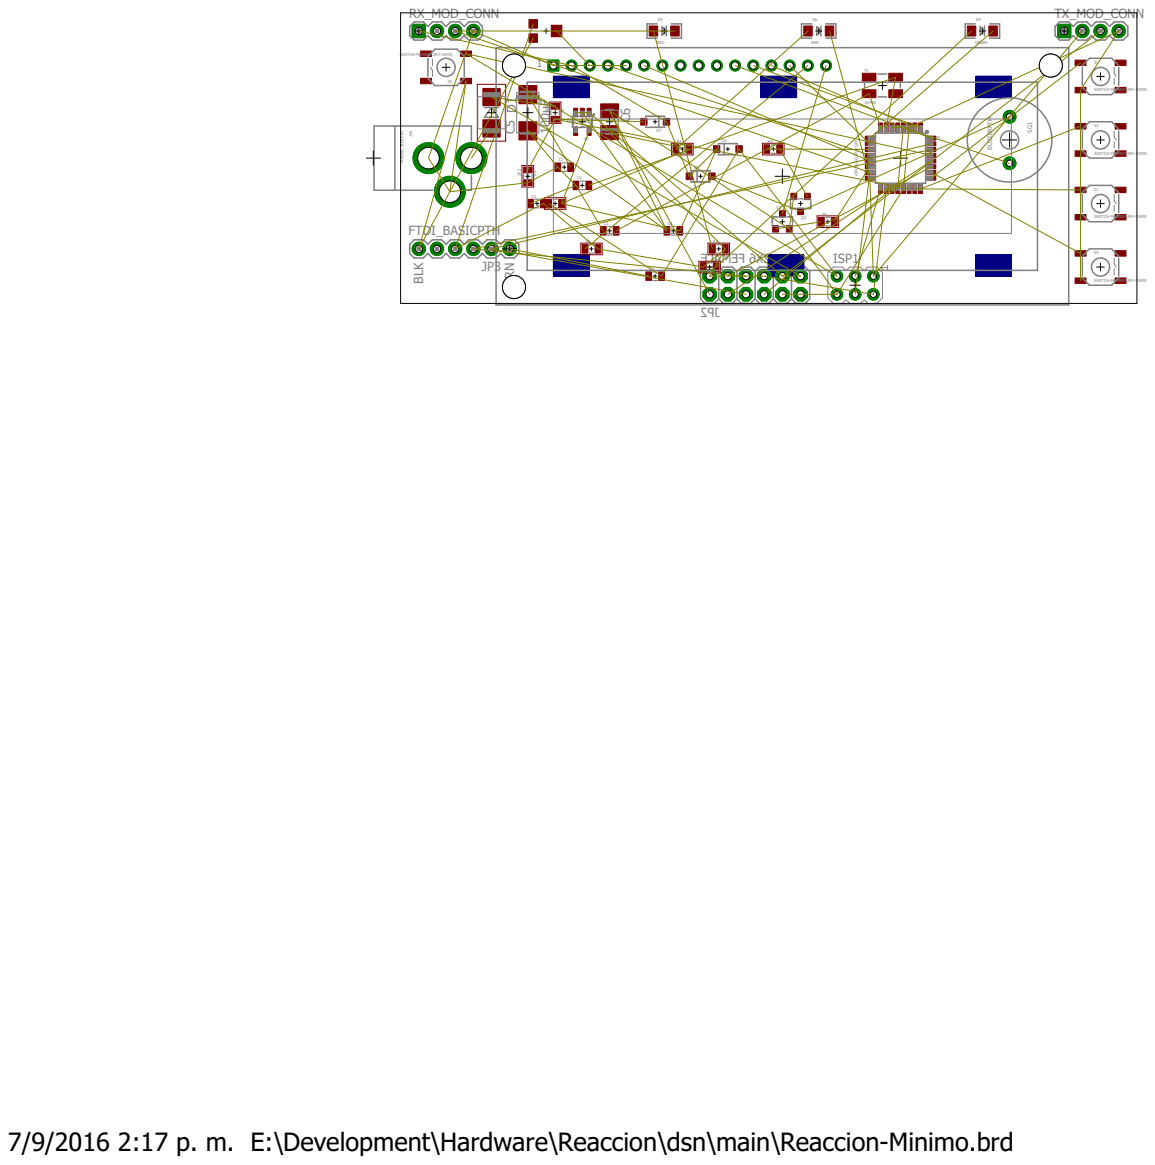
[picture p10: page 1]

7/9/2016 2:17 p. m. E:\Development\Hardware\Reaccion\dsn\main\Reaccion-Minimo.brd

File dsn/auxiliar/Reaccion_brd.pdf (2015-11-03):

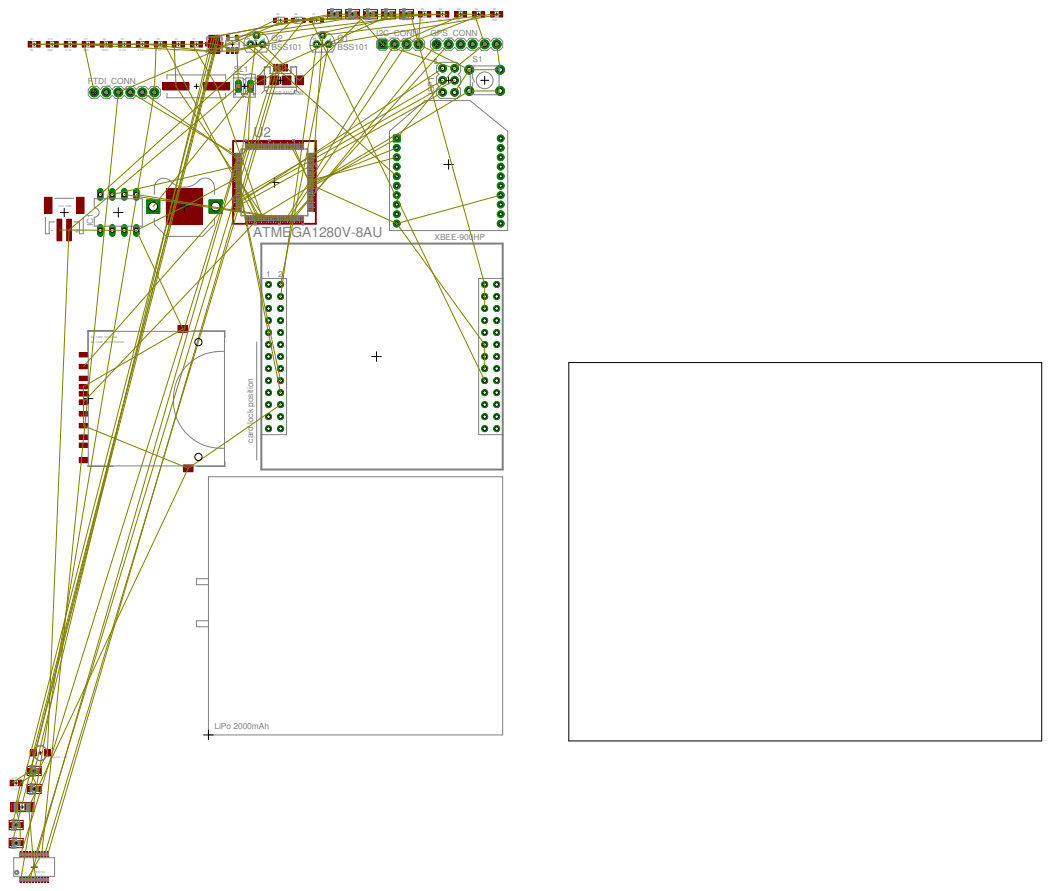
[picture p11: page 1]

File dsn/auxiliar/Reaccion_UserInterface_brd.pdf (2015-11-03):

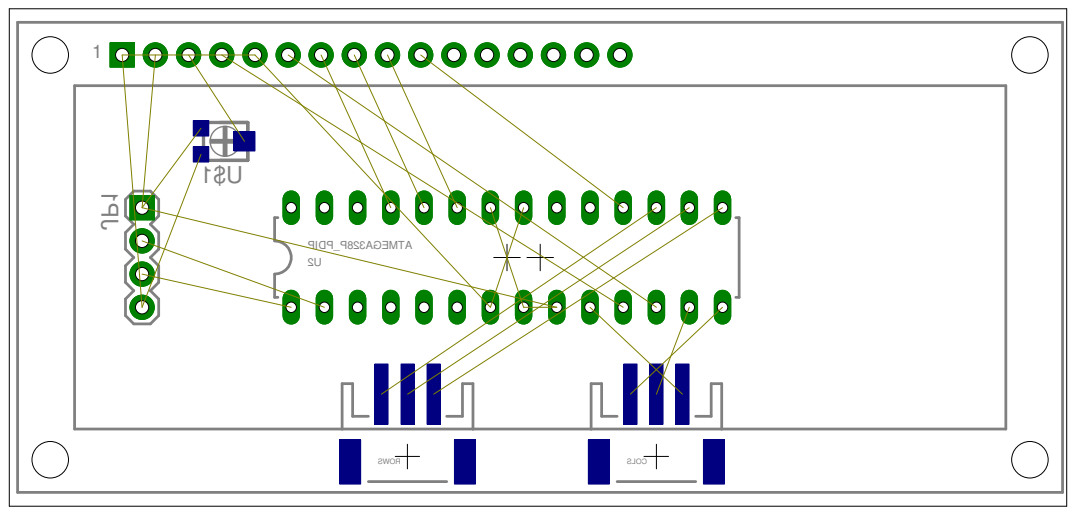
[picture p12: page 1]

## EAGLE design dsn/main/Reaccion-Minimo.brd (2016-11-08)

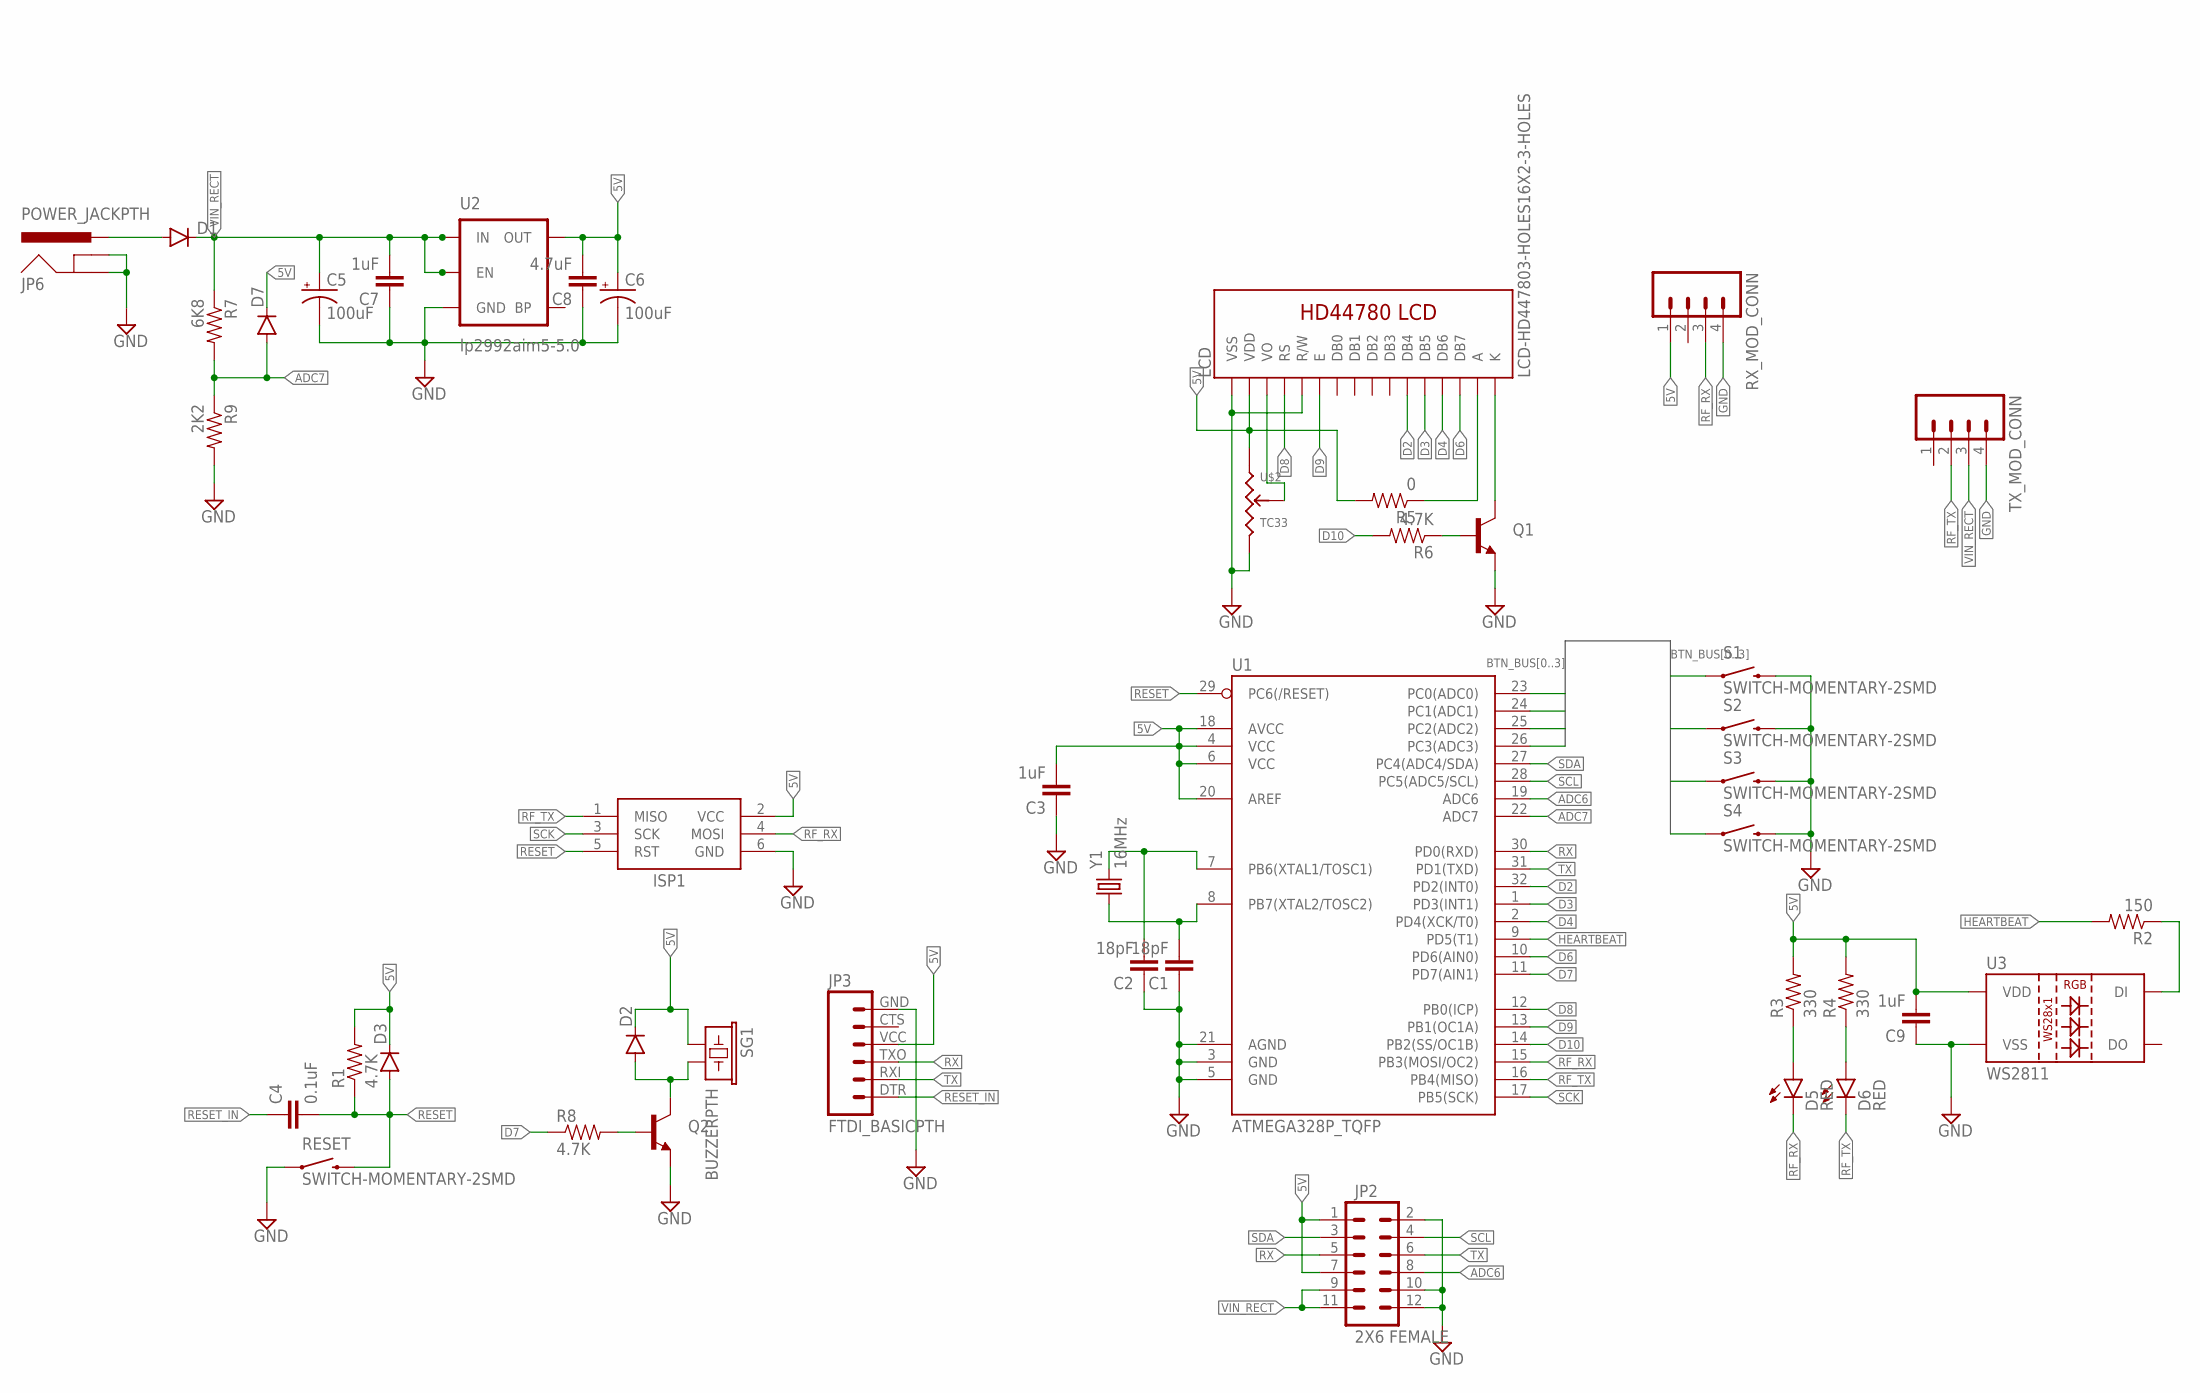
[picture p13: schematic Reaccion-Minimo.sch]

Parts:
C1, C2: 18pF; 0805
C3, C7, C9: 1uF; 0805
C4: 0.1uF; 0805
C5: 100uF; C/6032-28R
C6: 100uF; T/3528-12R
C8: 4.7uF; 0805
D1: DIODESMB; SMB-DIODE
D2, D3, D7: DIODESOD123; SOD-123
D5, D6: RED; LED-1206
ISP1: AVRISP-6; AVRISP
JP2: 2X6 FEMALE; 2X6
JP3: FTDI_BASICPTH; FTDI_BASIC
JP6: POWER_JACKPTH; POWER_JACK_PTH
LCD: LCD-HD447803-HOLES16X2-3-HOLES; LCD-16X2-3HOLES
Q1, Q2: TRANSISTOR_NPNSOT23-3; SOT23-3
R1, R6, R8: 4.7K; 0805
R2: 150; 0805
R3, R4: 330; 0805
R5: 0; 0805
R7: 6K8; 0805
R9: 2K2; 0805
RESET: SWITCH-MOMENTARY-2SMD; TACTILE-SWITCH-SMD
RX_MOD_CONN: M04PTH; 1X04
S1, S2, S3, S4: SWITCH-MOMENTARY-2SMD; TACTILE-SWITCH-SMD
SG1: BUZZERPTH; BUZZER-12MM
TX_MOD_CONN: M04PTH; 1X04
U1: ATMEGA328P_TQFP; TQFP32-08
U2: lp2992aim5-5.0; SOT23-5
U3: WS2811; LED-TRICOLOR-5050-IC
U$2: TC33
Y1: 16MHz; CRYSTAL-SMD-5X3

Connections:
5V: C3.2, C6.+, C8.2, C9.2, D2.C, D3.C, D7.C, ISP1.2 (VCC), JP2.1, JP2.7, JP3.VCC (4), LCD.2 (VDD), R1.2, R3.2, R4.2, R5.2, RX_MOD_CONN.1, SG1.+ (1), U1.4 (VCC), U1.6 (VCC), U1.18 (AVCC), U1.20 (AREF), U2.5 (OUT), U3.3 (VDD), U3.5 (VDD), U$2.1
ADC6: JP2.8, U1.19 (ADC6)
ADC7: D7.A, R7.2, R9.1, U1.22 (ADC7)
BTN_BUS0: S1.1, U1.23 (PC0(ADC0))
BTN_BUS1: S2.1, U1.24 (PC1(ADC1))
BTN_BUS2: S3.1, U1.25 (PC2(ADC2))
BTN_BUS3: S4.1, U1.26 (PC3(ADC3))
D2: LCD.11 (DB4), U1.32 (PD2(INT0))
D3: LCD.12 (DB5), U1.1 (PD3(INT1))
D4: LCD.13 (DB6), U1.2 (PD4(XCK/T0))
D6: LCD.14 (DB7), U1.10 (PD6(AIN0))
D7: R8.1, U1.11 (PD7(AIN1))
D8: LCD.4 (RS), U1.12 (PB0(ICP))
D9: LCD.6 (E), U1.13 (PB1(OC1A))
D10: R6.2, U1.14 (PB2(SS/OC1B))
GND: C1.1, C2.1, C3.1, C5.-, C6.-, C7.1, C8.1, C9.1, ISP1.6 (GND), JP2.2, JP2.10, JP2.12, JP3.GND (6), JP6.GND, JP6.GNDBREAK, LCD.1 (VSS), LCD.5 (R/W), Q1.2 (E), Q2.2 (E), R9.2, RESET.1, RX_MOD_CONN.4, S1.3 (2), S2.3 (2), S3.3 (2), S4.3 (2), TX_MOD_CONN.4, U1.3 (GND), U1.5 (GND), U1.21 (AGND), U2.2 (GND), U3.6 (VSS), U$2.3
HEARTBEAT: R2.2, U1.9 (PD5(T1))
unnamed: C2.2, U1.7 (PB6(XTAL1/TOSC1)), Y1.3 (2)
unnamed: C1.2, U1.8 (PB7(XTAL2/TOSC2)), Y1.1
unnamed: R2.1, U3.2 (DI)
unnamed: D5.A, R3.1
unnamed: D6.A, R4.1
unnamed: LCD.15 (A), R5.1
unnamed: LCD.3 (VO), U$2.2
unnamed: LCD.16 (K), Q1.3 (C)
unnamed: Q1.1 (B), R6.1
unnamed: D2.A, Q2.3 (C), SG1.- (2)
unnamed: Q2.1 (B), R8.2
RESET: C4.2, D3.A, ISP1.5 (RST), R1.1, RESET.3 (2), U1.29 (PC6(/RESET))
RESET_IN: C4.1, JP3.DTR (1)
RF_RX: D5.C, ISP1.4 (MOSI), RX_MOD_CONN.3, U1.15 (PB3(MOSI/OC2))
RF_TX: D6.C, ISP1.1 (MISO), TX_MOD_CONN.2, U1.16 (PB4(MISO))
RX: JP2.5, JP3.TXO (3), U1.30 (PD0(RXD))
SCK: ISP1.3 (SCK), U1.17 (PB5(SCK))
SCL: JP2.4, U1.28 (PC5(ADC5/SCL))
SDA: JP2.3, U1.27 (PC4(ADC4/SDA))
TX: JP2.6, JP3.RXI (2), U1.31 (PD1(TXD))
VIN: D1.A, JP6.PWR
VIN_RECT: C5.+, C7.2, D1.C, JP2.9, JP2.11, R7.1, TX_MOD_CONN.3, U2.1 (IN), U2.3 (EN)

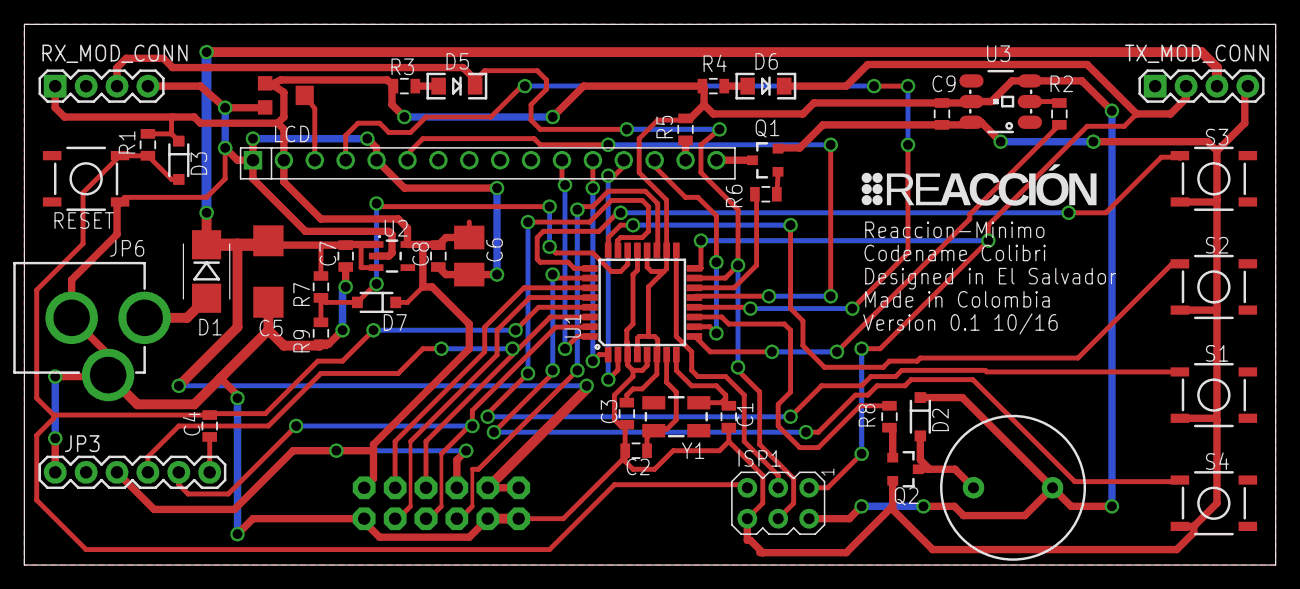
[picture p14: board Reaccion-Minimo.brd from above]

Board: 2 copper layers, 102.9 x 44.5 mm, 44 parts (1 on the bottom side), 39 nets.

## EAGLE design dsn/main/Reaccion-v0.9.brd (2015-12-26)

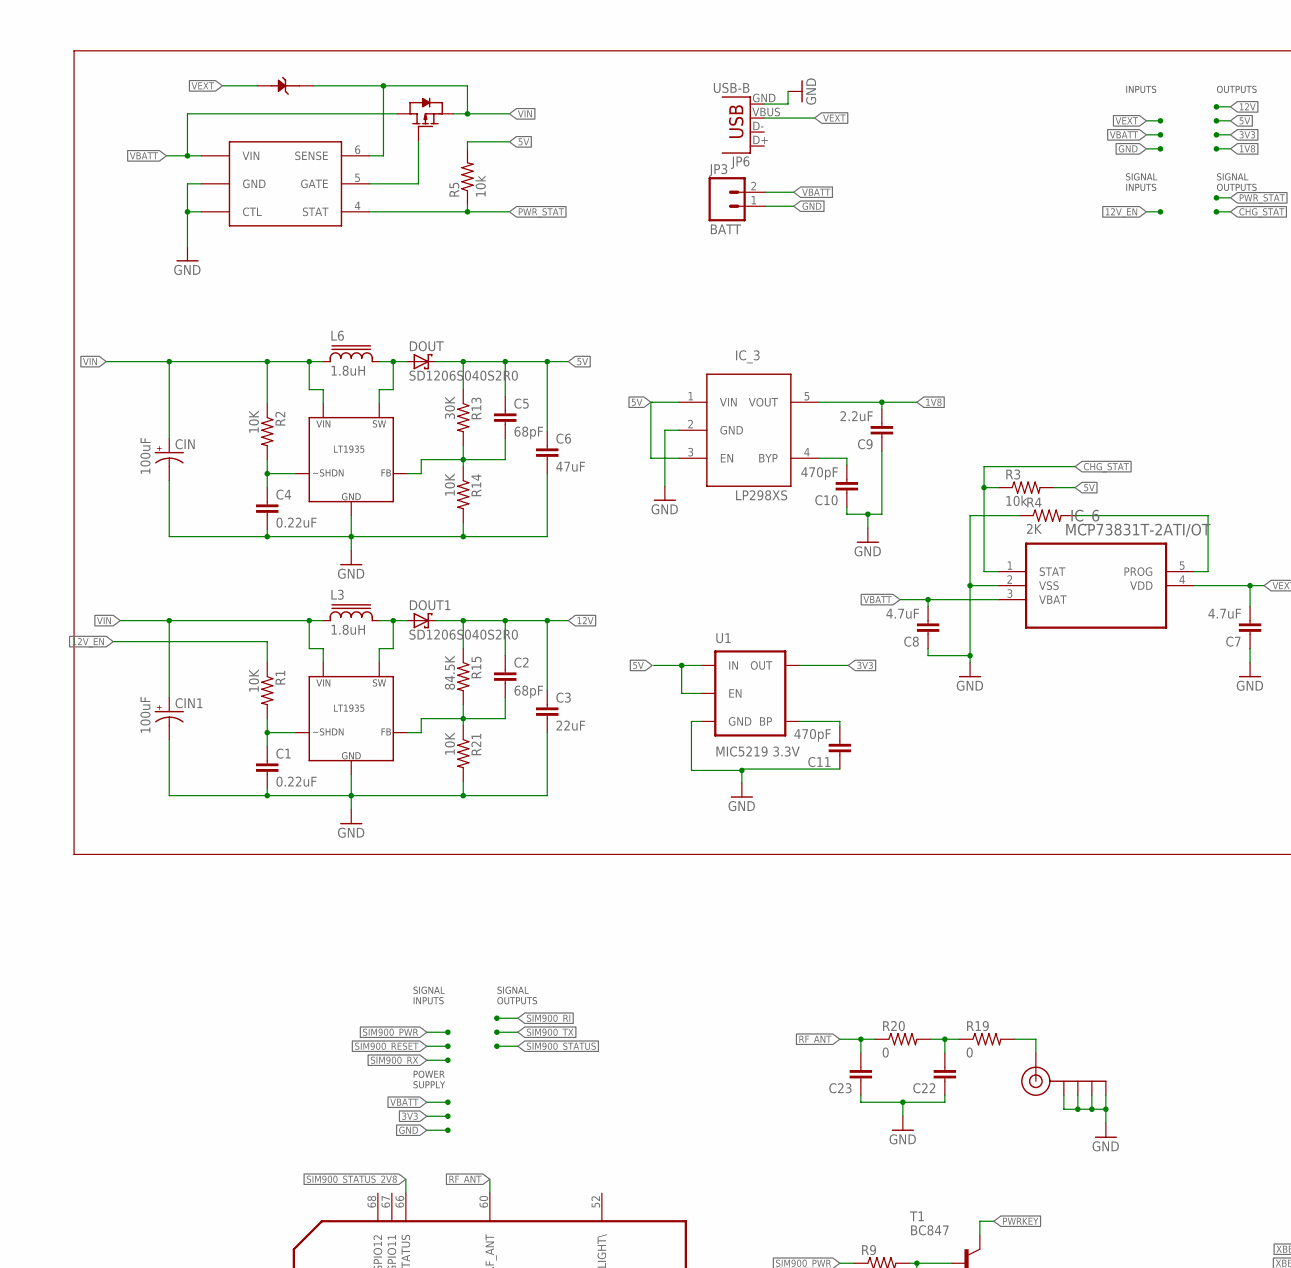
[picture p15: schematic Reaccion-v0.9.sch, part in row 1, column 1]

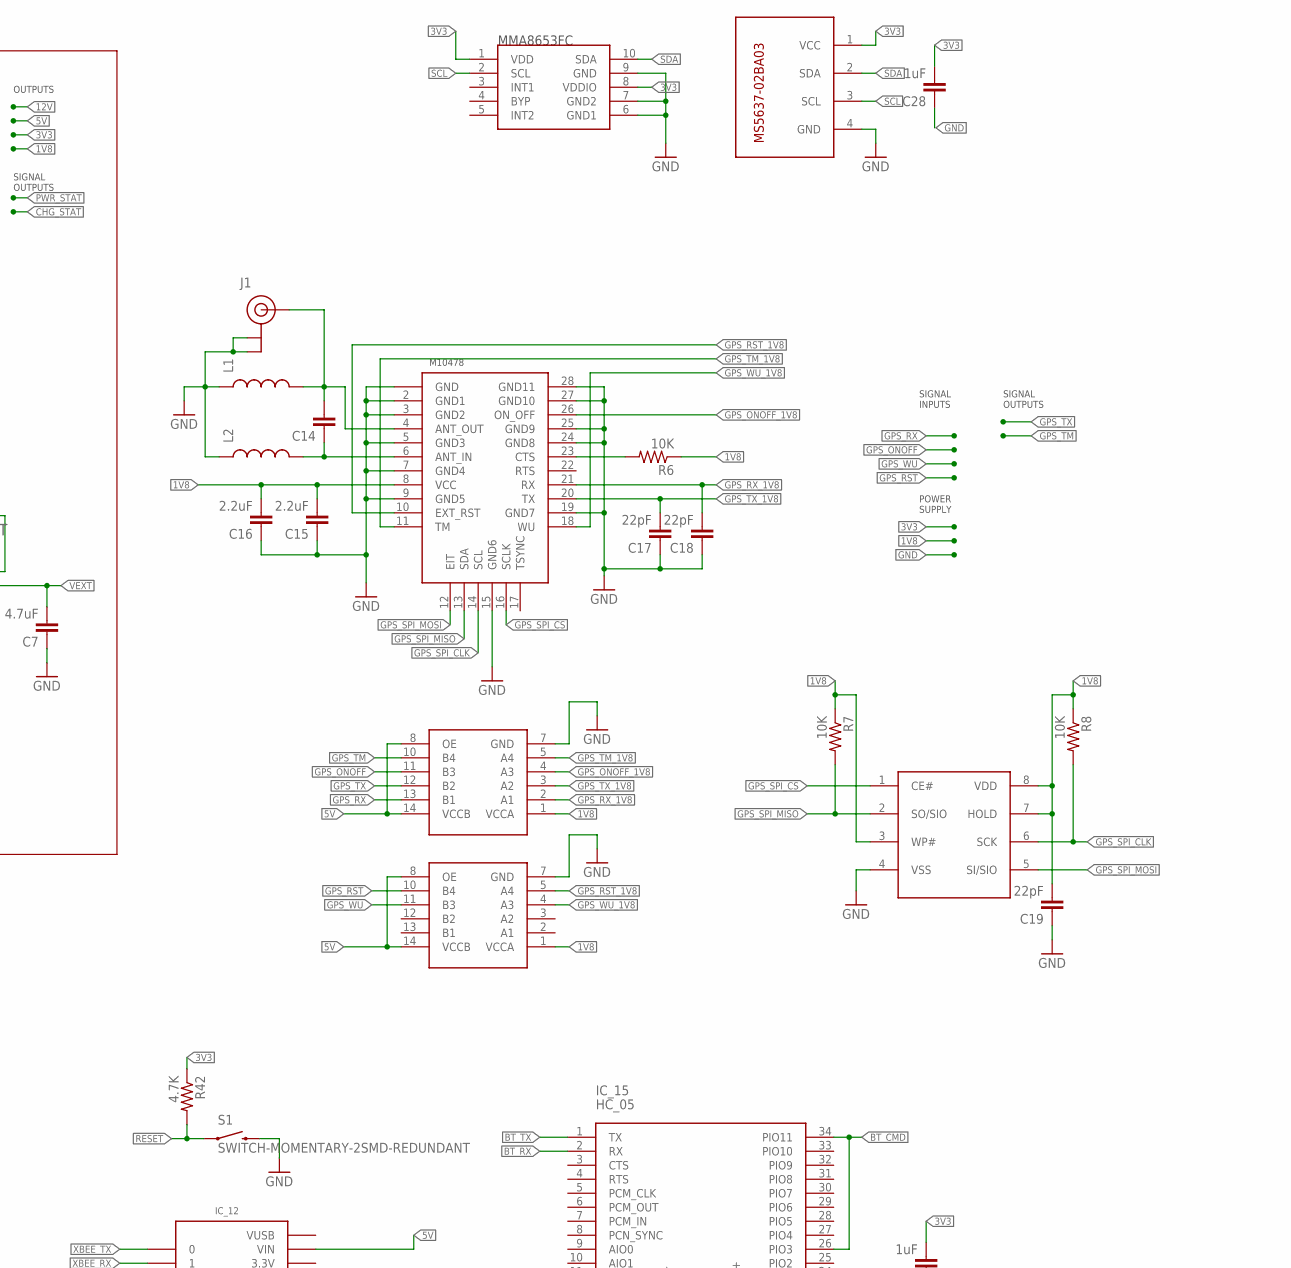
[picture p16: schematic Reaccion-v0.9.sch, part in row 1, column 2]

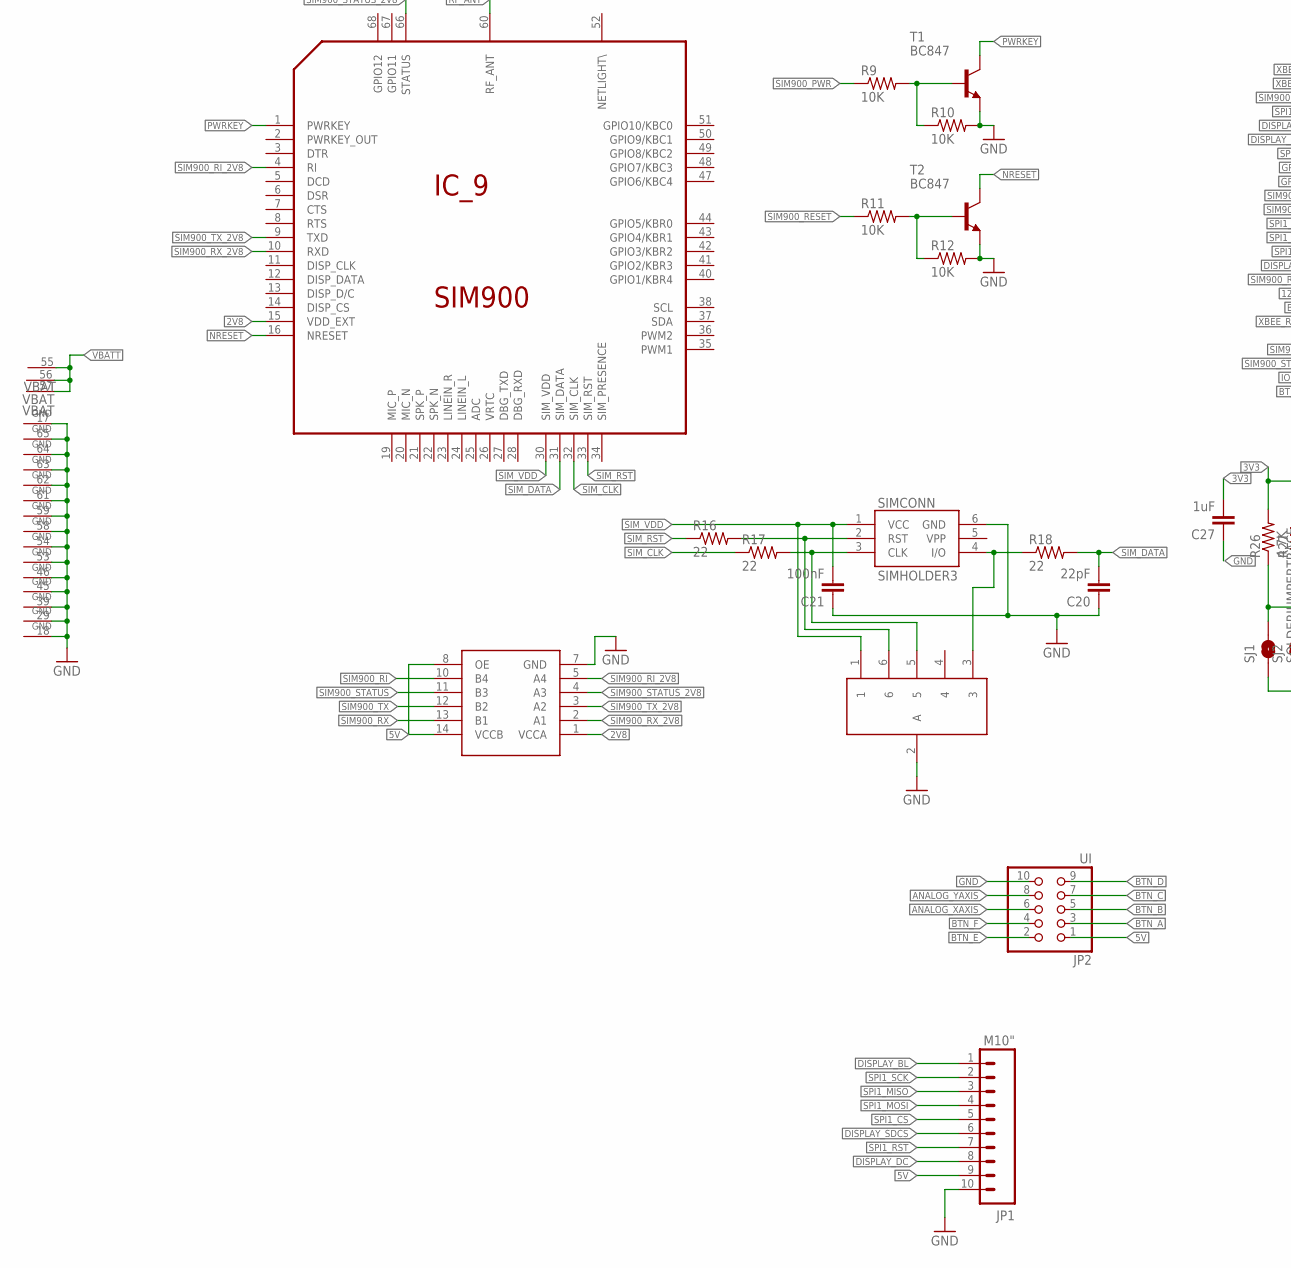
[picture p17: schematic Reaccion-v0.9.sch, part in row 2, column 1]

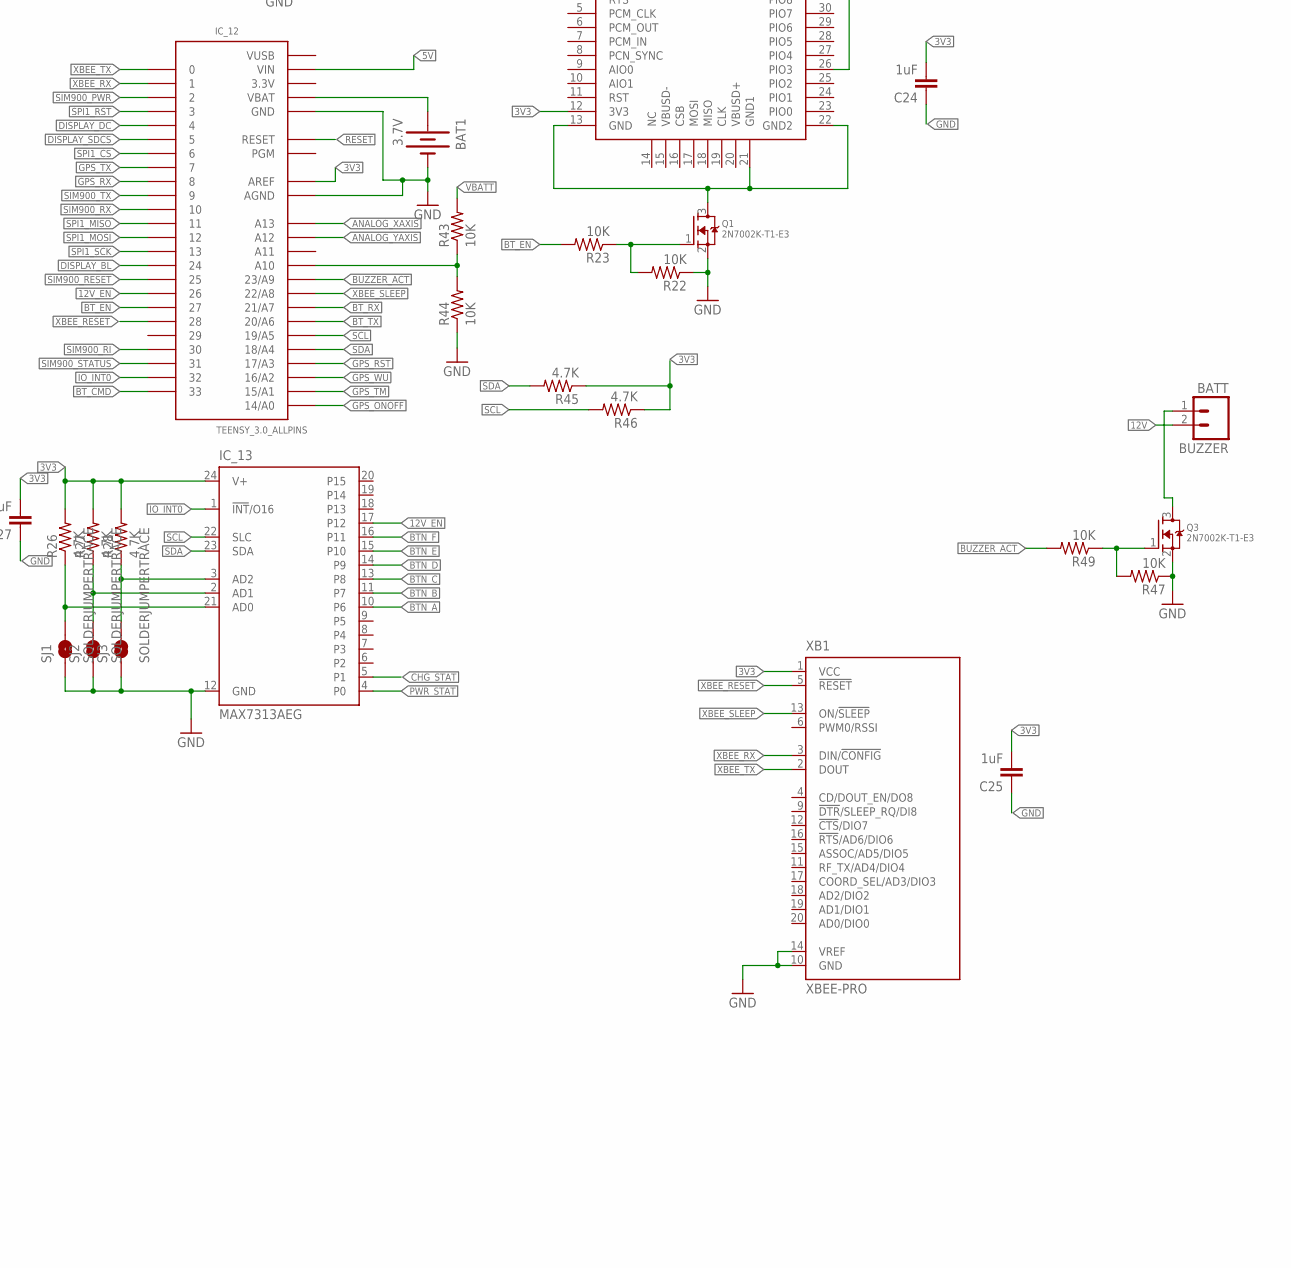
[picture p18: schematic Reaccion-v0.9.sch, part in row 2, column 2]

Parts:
BAT1: 3.7V; BATTCON_12MM
BUZZER: BATT; JST-2-PTH-NS
C1, C4: 0.22uF; 0805
C2, C5: 68pF; 0805
C3: 22uF; 0805
C6: 47uF; 0805
C7, C8: 4.7uF; 0805
C9, C15, C16: 2.2uF; 0805
C10, C11: 470pF; 0805
C14, C22, C23: CAP0805; 0805
C17, C18, C19, C20: 22pF; 0805
C21: 100nF; 0805
C24, C25, C27, C28: 1uF; 0805
CIN, CIN1: 100uF; 1210-POLARIZED
D4: 1N5819HW-7-F; SOD123
DOUT, DOUT1: SD1206S040S2R0; 1206-POL
IC_1: LTC4412; SOT23-6L
IC_3: LP298XS; SOT23-5L
IC_6: MCP73831T-2ATI/OT; SOT95P300X145-5N
IC_7: MMA8653FC; 2X2-DFN
IC_8: MS5637-02BA03
IC_9: SIM900
IC_10, IC_17, IC_18: TXB0104; SO14
IC_11: SMF05C; SOT665
IC_12: TEENSY_3.0_ALLPINS
IC_13: MAX7313AEG; QSOP24
IC_15: HC_05; BLUETOOTH_SMD
IC_16: M10478
IC_19: SST25WF040B; SO08
J1: U.FL
J$1: SMA_EDGE; SMA-EDGE
JP1: M10"; 1X10
JP2: UI; 2X05
JP3: BATT; JST-2-PTH-NS
JP6: USB-B; USB-B-PTH
L1, L2: INDUCTOR0805; 0805
L3, L6: 1.8uH; SRR4028
Q1, Q3: 2N7002K-T1-E3; SOT23
Q9: SI2301CDS; SOT23
R1, R2, R6, R7, R8, R9, R10, R11, R12, R14, R21, R22, R23, R43, R44, R47, R49: 10K; 0805
R3, R5: 10k; 0805
R4: 2K; 0805
R13: 30K; 0805
R15: 84.5K; 0805
R16, R17, R18: 22; 0805
R19, R20: 0; 0805
R26, R27, R28, R42, R45, R46: 4.7K; 0805
S1: SWITCH-MOMENTARY-2SMD-REDUNDANT; TACTILE-SWITCH-SMD
SIMCONN: SIMHOLDER3
SJ1, SJ2, SJ3: SOLDERJUMPERTRACE; SJ_2S-TRACE
T1, T2: BC847; SOT23
U1: MIC5219 3.3V; SOT23-5
U$1, U$2: LT1935ES5; SOT23-5
XB1: XBEE-PRO

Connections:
1V8: C9.2, C15.2, C16.2, C19.2, IC_3.5 (VOUT), IC_16.8 (VCC), IC_17.1 (VCCA), IC_18.1 (VCCA), IC_19.3 (WP#), IC_19.7 (HOLD), IC_19.8 (VDD), R6.1, R7.1, R8.1
2V8: IC_9.15 (VDD_EXT), IC_10.1 (VCCA)
3.3V: IC_12.3.3V, IC_12.3.3V1 (3.3V), IC_12.3.3V2 (3.3V)
3V3: C24.2, C25.2, C27.2, C28.2, IC_7.1 (VDD), IC_7.8 (VDDIO), IC_8.1 (VCC), IC_12.AREF, IC_13.24 (V+), IC_15.12 (3V3), R26.2, R27.2, R28.2, R42.1, R45.1, R46.1, U1.5 (OUT), XB1.1 (VCC)
5V: C5.1, C6.1, DOUT.2 (C), IC_3.1 (VIN), IC_3.3 (EN), IC_10.8 (OE), IC_10.14 (VCCB), IC_12.VIN, IC_17.8 (OE), IC_17.14 (VCCB), IC_18.8 (OE), IC_18.14 (VCCB), JP1.9, JP2.1, R3.2, R5.2, R13.1, U1.1 (IN), U1.3 (EN)
12V: BUZZER.2, C2.1, C3.1, DOUT1.2 (C), R15.1
12V_EN: IC_12.26, IC_13.17 (P12), R1.1
ANALOG_XAXIS: IC_12.A13, JP2.6
ANALOG_YAXIS: IC_12.A12, JP2.8
BTN_A: IC_13.10 (P6), JP2.3
BTN_B: IC_13.11 (P7), JP2.5
BTN_C: IC_13.13 (P8), JP2.7
BTN_D: IC_13.14 (P9), JP2.9
BTN_E: IC_13.15 (P10), JP2.2
BTN_F: IC_13.16 (P11), JP2.4
BT_CMD: IC_12.33, IC_15.26 (PIO3), IC_15.34 (PIO11)
BT_EN: IC_12.27, R23.2
BT_RX: IC_12.21/A7, IC_15.2 (RX)
BT_TX: IC_12.20/A6, IC_15.1 (TX)
BUZZER_ACT: IC_12.23/A9, R49.2
CHG_STAT: IC_6.1 (STAT), IC_13.5 (P1), R3.1
DISPLAY_BL: IC_12.24, JP1.1
DISPLAY_DC: IC_12.4, JP1.8
DISPLAY_SDCS: IC_12.5, JP1.6
GND: BAT1.GND (-), C1.2, C3.2, C4.2, C6.2, C7.1, C8.1, C9.1, C10.1, C11.1, C15.1, C16.1, C17.1, C18.1, C19.1, C20.1, C21.1, C22.1, C23.1, C24.1, C25.1, C27.1, C28.1, CIN.2 (-), CIN1.2 (-), IC_1.2 (GND), IC_1.3 (CTL), IC_3.2 (GND), IC_6.2 (VSS), IC_7.6 (GND1), IC_7.7 (GND2), IC_7.9 (GND), IC_8.4 (GND), IC_9.17 (GND), IC_9.18 (GND), IC_9.29 (GND), IC_9.39 (GND), IC_9.45 (GND), IC_9.46 (GND), IC_9.53 (GND), IC_9.54 (GND), IC_9.58 (GND), IC_9.59 (GND), IC_9.61 (GND), IC_9.62 (GND), IC_9.63 (GND), IC_9.64 (GND), IC_9.65 (GND), IC_10.7 (GND), IC_11.2 (A), IC_12.AGND, IC_12.GND, IC_12.GND1 (GND), IC_12.GND2 (GND), IC_13.12 (GND), IC_16.1 (GND), IC_16.2 (GND1), IC_16.3 (GND2), IC_16.5 (GND3), IC_16.7 (GND4), IC_16.9 (GND5), IC_16.15 (GND6), IC_16.19 (GND7), IC_16.24 (GND8), IC_16.25 (GND9), IC_16.27 (GND10), IC_16.28 (GND11), IC_17.7 (GND), IC_18.7 (GND), IC_19.4 (VSS), J1.P$1 (GND), J1.P$2 (GND), J$1.GND@0 (GND), J$1.GND@1 (GND), J$1.GND@2 (GND), J$1.GND@3 (GND), JP1.10, JP2.10, JP3.1, JP6.GND, L1.1, L2.1, Q1.2 (S), Q3.2 (S), R4.1, R10.2, R12.2, R14.2, R21.2, R22.1, R44.1, R47.1, S1.3 (2), S1.4 (2), SIMCONN.6 (GND), SJ1.1, SJ2.1, SJ3.1, T1.2 (E), T2.2 (E), U1.2 (GND), U$1.2 (GND), U$2.2 (GND), XB1.10 (GND), XB1.14 (VREF)
GPS_ONOFF: IC_12.14/A0, IC_17.11 (B3)
GPS_ONOFF_1V8: IC_16.26 (ON_OFF), IC_17.4 (A3)
GPS_RST: IC_12.17/A3, IC_18.10 (B4)
GPS_RST_1V8: IC_16.10 (EXT_RST), IC_18.5 (A4)
GPS_RX: IC_12.8, IC_17.13 (B1)
GPS_RX_1V8: C18.2, IC_16.21 (RX), IC_17.2 (A1)
GPS_SPI_CLK: IC_16.14 (SCL), IC_19.6 (SCK), R8.2
GPS_SPI_CS: IC_16.16 (SCLK), IC_19.1 (CE#)
GPS_SPI_MISO: IC_16.13 (SDA), IC_19.2 (SO/SIO), R7.2
GPS_SPI_MOSI: IC_16.12 (EIT), IC_19.5 (SI/SIO)
GPS_TM: IC_12.15/A1, IC_17.10 (B4)
GPS_TM_1V8: IC_16.11 (TM), IC_17.5 (A4)
GPS_TX: IC_12.7, IC_17.12 (B2)
GPS_TX_1V8: C17.2, IC_16.20 (TX), IC_17.3 (A2)
GPS_WU: IC_12.16/A2, IC_18.11 (B3)
GPS_WU_1V8: IC_16.18 (WU), IC_18.4 (A3)
IO_INT0: IC_12.32, IC_13.1 (!INT!/O16)
unnamed: DOUT1.1 (A), L3.2, U$2.1 (SW)
unnamed: DOUT.1 (A), L6.2, U$1.1 (SW)
unnamed: C1.1, R1.2, U$2.4 (SHDN)
unnamed: C11.2, U1.4 (BP)
unnamed: C2.2, R15.2, R21.1, U$2.3 (FB)
unnamed: C5.2, R13.2, R14.1, U$1.3 (FB)
unnamed: C4.1, R2.2, U$1.4 (SHDN)
unnamed: IC_6.5 (PROG), R4.2
unnamed: IC_1.5 (GATE), Q9.1 (GATE)
unnamed: C10.2, IC_3.4 (BYP)
unnamed: C14.1, IC_16.6 (ANT_IN), L2.2
unnamed: C14.2, IC_16.4 (ANT_OUT), J1.P$3 (SIGNAL), L1.2
unnamed: BUZZER.1, Q3.3 (D)
unnamed: IC_16.23 (CTS), R6.2
unnamed: R9.2, R10.1, T1.1 (B)
unnamed: R11.2, R12.1, T2.1 (B)
unnamed: IC_15.13 (GND), IC_15.21 (GND1), IC_15.22 (GND2), Q1.3 (D)
unnamed: IC_11.3, R18.1, SIMCONN.4 (I/O)
unnamed: C22.2, R19.1, R20.2
unnamed: IC_11.6, R16.2, SIMCONN.2 (RST)
unnamed: IC_11.5, R17.2, SIMCONN.3 (CLK)
unnamed: J$1.SIG (SIGNAL), R19.2
unnamed: Q1.1 (G), R22.2, R23.1
unnamed: Q3.1 (G), R47.2, R49.1
unnamed: IC_13.21 (AD0), R26.1, SJ1.2
unnamed: IC_13.3 (AD2), R28.1, SJ3.2
unnamed: IC_13.2 (AD1), R27.1, SJ2.2
unnamed: BAT1.PWR@1 (+), IC_12.VBAT
unnamed: IC_12.A10, R43.1, R44.2
NRESET: IC_9.16 (NRESET), T2.3 (C)
PWRKEY: IC_9.1 (PWRKEY), T1.3 (C)
PWR_STAT: IC_1.4 (STAT), IC_13.4 (P0), R5.1
RESET: IC_12.RESET, R42.2, S1.1, S1.2 (1)
RF_ANT: C23.2, IC_9.60 (RF_ANT), R20.1
SCL: IC_7.2 (SCL), IC_8.3 (SCL), IC_12.19/A5, IC_13.22 (SLC), R46.2
SDA: IC_7.10 (SDA), IC_8.2 (SDA), IC_12.18/A4, IC_13.23 (SDA), R45.2
SIM900_PWR: IC_12.2, R9.1
SIM900_RESET: IC_12.25, R11.1
SIM900_RI: IC_10.10 (B4), IC_12.30
SIM900_RI_2V8: IC_9.4 (RI), IC_10.5 (A4)
SIM900_RX: IC_10.13 (B1), IC_12.10
SIM900_RX_2V8: IC_9.10 (RXD), IC_10.2 (A1)
SIM900_STATUS: IC_10.11 (B3), IC_12.31
SIM900_STATUS_2V8: IC_9.66 (STATUS), IC_10.4 (A3)
SIM900_TX: IC_10.12 (B2), IC_12.9
SIM900_TX_2V8: IC_9.9 (TXD), IC_10.3 (A2)
SIM_CLK: IC_9.32 (SIM_CLK), R17.1
SIM_DATA: C20.2, IC_9.31 (SIM_DATA), R18.2
SIM_RST: IC_9.33 (SIM_RST), R16.1
SIM_VDD: C21.2, IC_9.30 (SIM_VDD), IC_11.1, SIMCONN.1 (VCC)
SPI1_CS: IC_12.6, JP1.5
SPI1_MISO: IC_12.11, JP1.3
SPI1_MOSI: IC_12.12, JP1.4
SPI1_RST: IC_12.3, JP1.7
SPI1_SCK: IC_12.13, JP1.2
VBATT: C8.2, IC_1.1 (VIN), IC_6.3 (VBAT), IC_9.55 (VBAT), IC_9.56 (VBAT), IC_9.57 (VBAT), JP3.2, Q9.3 (DRAIN), R43.2
VEXT: C7.2, D4.2 (ANODE), IC_6.4 (VDD), JP6.VBUS
VIN: CIN.1 (+), CIN1.1 (+), D4.1 (CATHODE), IC_1.6 (SENSE), L3.1, L6.1, Q9.2 (SOURCE), R2.1, U$1.5 (VIN), U$2.5 (VIN)
VUSB: IC_12.VUSB
XBEE_RESET: IC_12.28, XB1.5 (!RESET)
XBEE_RX: IC_12.1, XB1.3 (DIN/!CONFIG)
XBEE_SLEEP: IC_12.22/A8, XB1.13 (ON/!SLEEP)
XBEE_TX: IC_12.0, XB1.2 (DOUT)

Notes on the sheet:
INPUTS
OUTPUTS
SIGNAL INPUTS
SIGNAL OUTPUTS
POWER SUPPLY

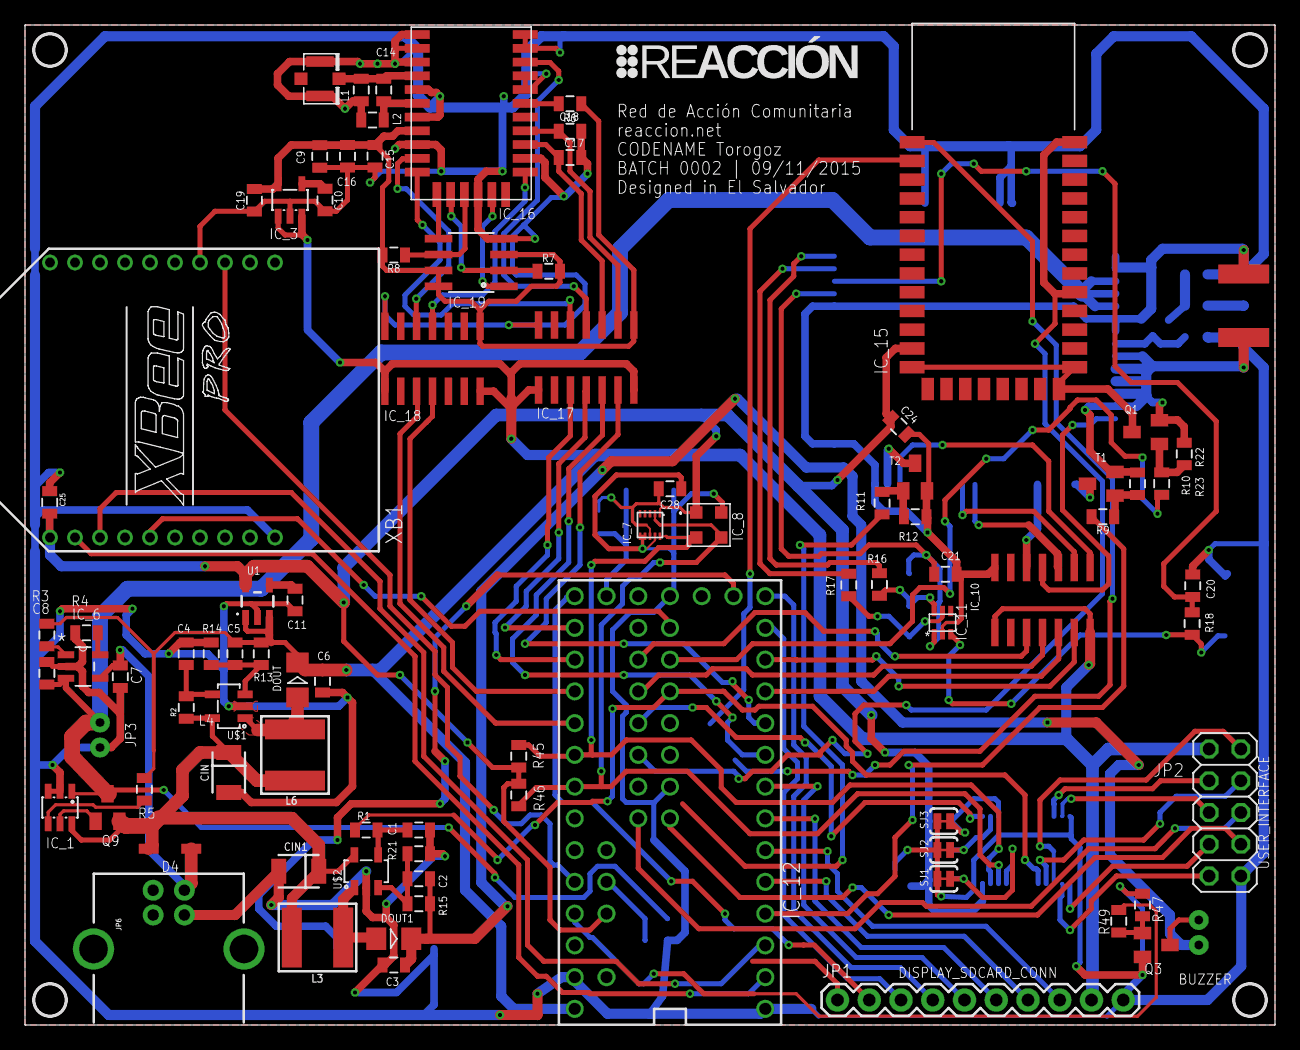
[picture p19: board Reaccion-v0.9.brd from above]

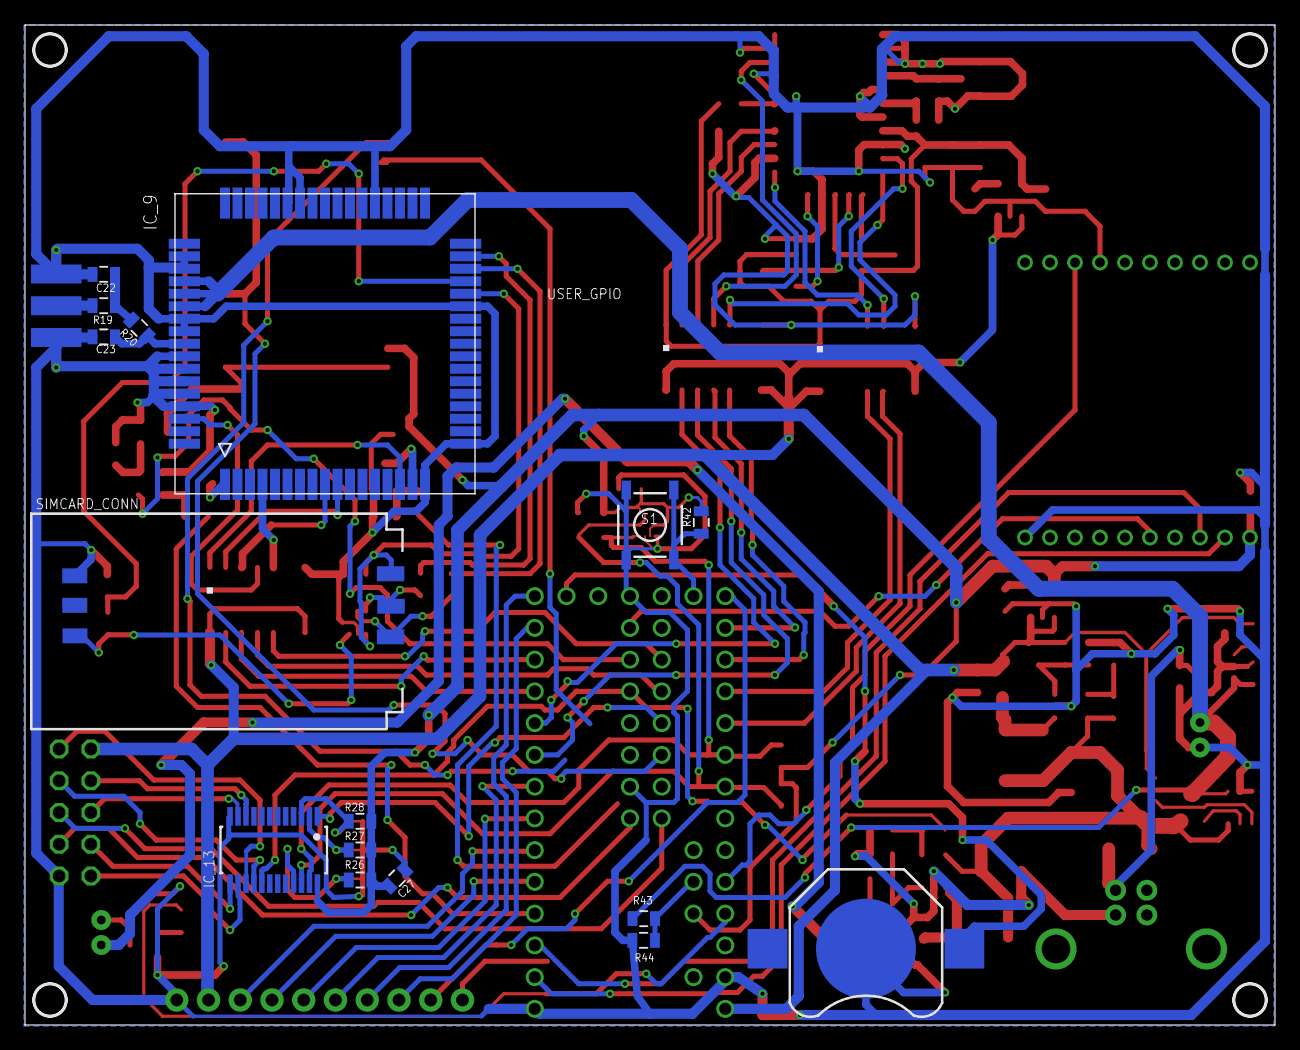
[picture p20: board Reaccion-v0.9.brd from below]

Board: 2 copper layers, 100.0 x 80.0 mm, 104 parts (17 on the bottom side), 104 nets.

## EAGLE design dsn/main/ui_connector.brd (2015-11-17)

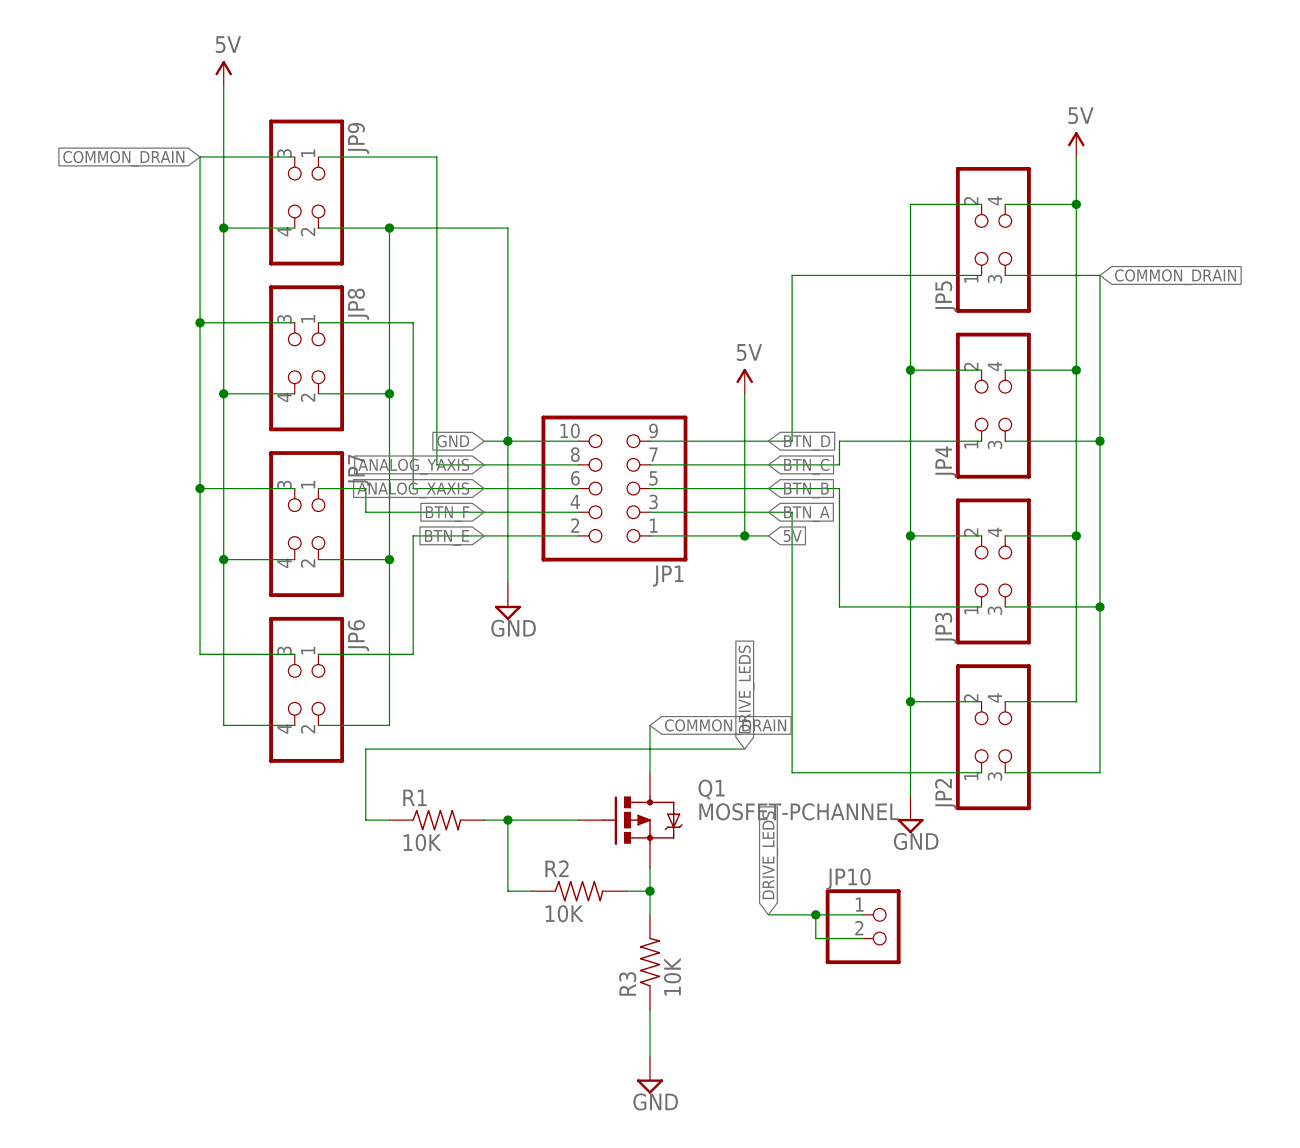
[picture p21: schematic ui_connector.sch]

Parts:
JP1: PINHD-2X5; 2X05
JP2, JP3, JP4, JP5, JP6, JP7, JP8, JP9: PINHD-2X2; 2X02
JP10: PINHD-1X2; 1X02
Q1: MOSFET-PCHANNEL; SOT23-3
R1, R2, R3: 10K; 0805

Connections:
5V: JP1.1, JP2.4, JP3.4, JP4.4, JP5.4, JP6.4, JP7.4, JP8.4, JP9.4
ANALOG_XAXIS: JP1.6, JP8.1
ANALOG_YAXIS: JP1.8, JP9.1
BTN_A: JP1.3, JP2.1
BTN_B: JP1.5, JP3.1
BTN_C: JP1.7, JP4.1
BTN_D: JP1.9, JP5.1
BTN_E: JP1.2, JP6.1
BTN_F: JP1.4, JP7.1
COMMON_DRAIN: JP2.3, JP3.3, JP4.3, JP5.3, JP6.3, JP7.3, JP8.3, JP9.3, Q1.3 (D)
DRIVE_LEDS: JP10.1, JP10.2, R1.1
GND: JP1.10, JP2.2, JP3.2, JP4.2, JP5.2, JP6.2, JP7.2, JP8.2, JP9.2, R3.1
unnamed: Q1.2 (S), R2.2, R3.2
unnamed: Q1.1 (G), R1.2, R2.1

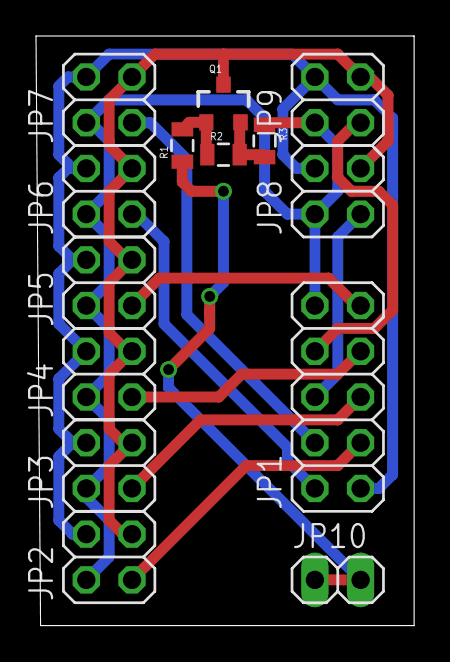
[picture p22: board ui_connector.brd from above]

Board: 2 copper layers, 21.0 x 32.8 mm, 14 parts (0 on the bottom side), 14 nets.

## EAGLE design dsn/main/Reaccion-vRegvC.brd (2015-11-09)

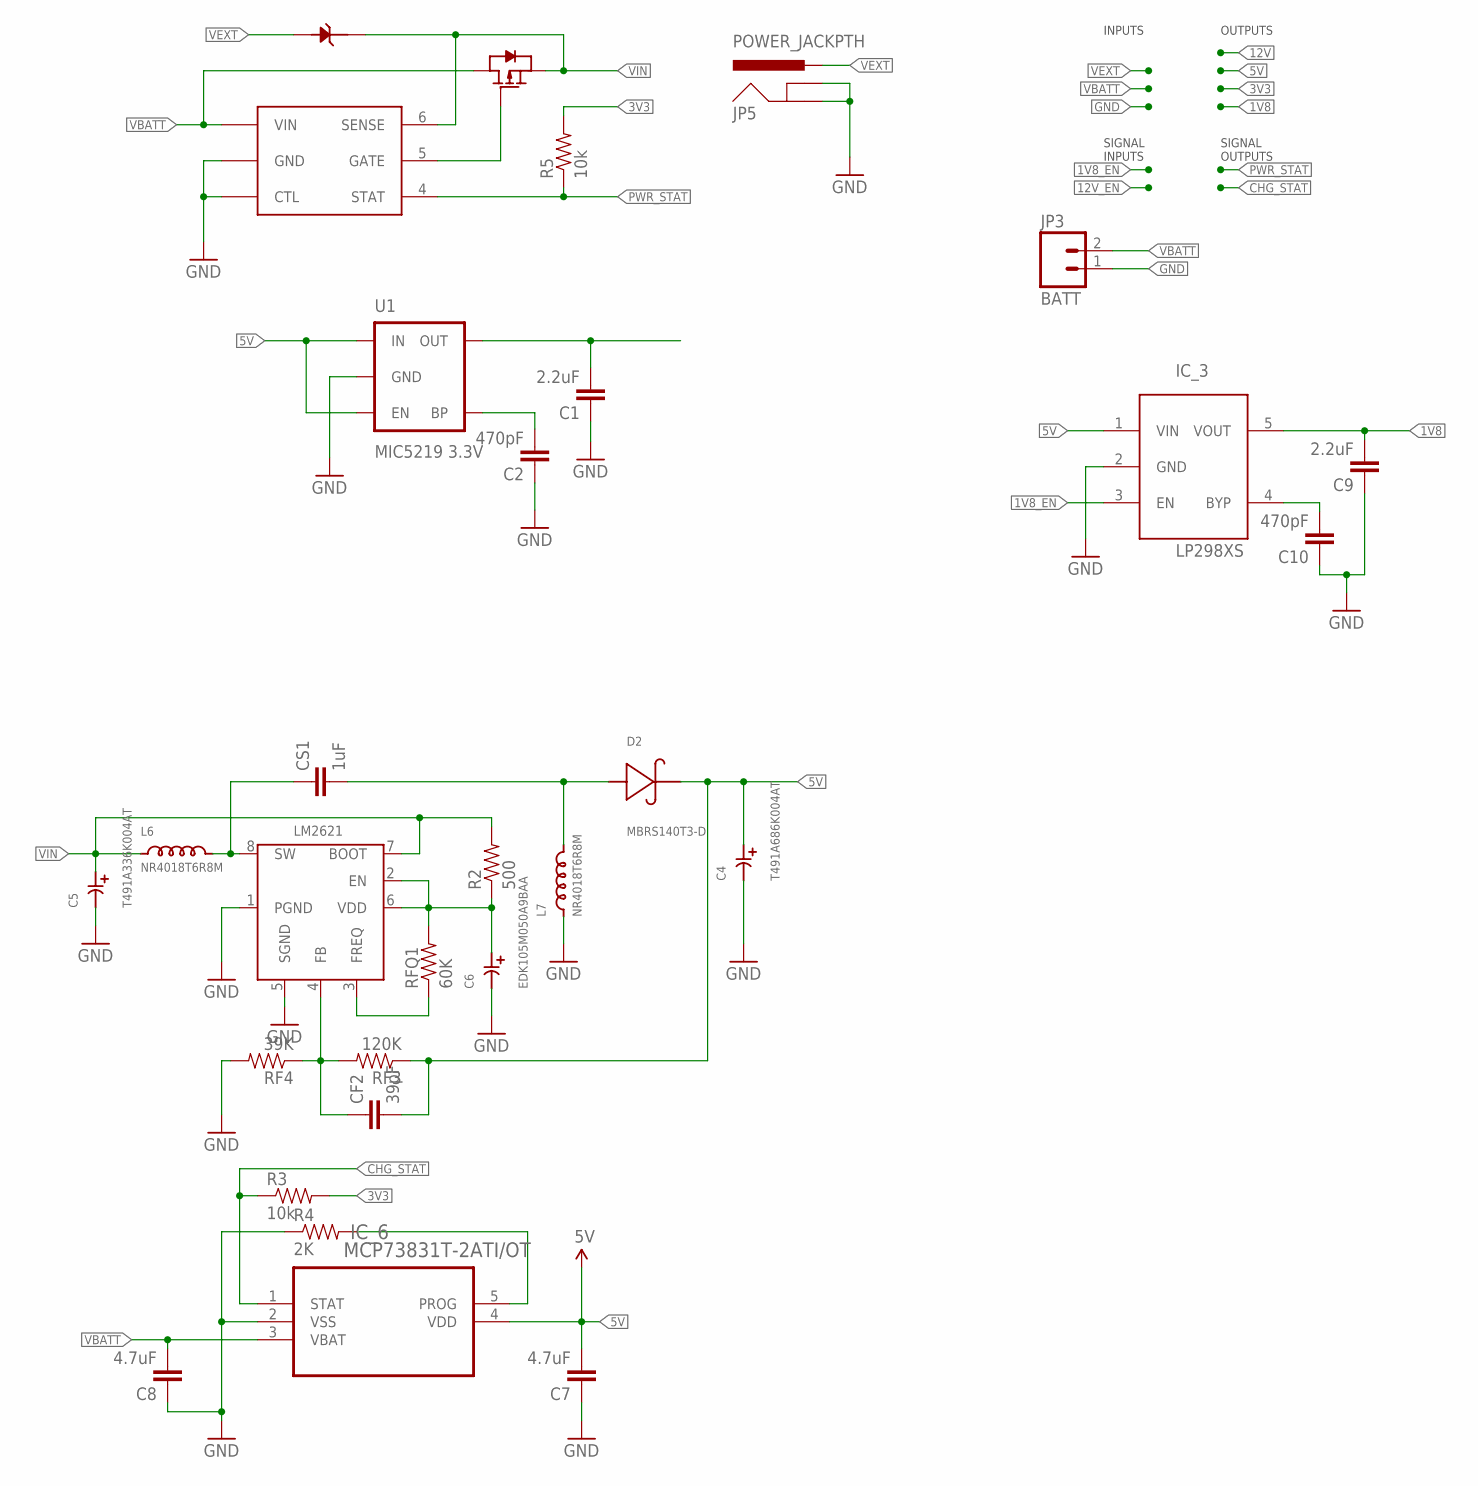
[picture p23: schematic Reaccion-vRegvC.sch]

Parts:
C1, C9: 2.2uF; 0805
C2, C10: 470pF; 0805
C4: T491A686K004AT; 3216-18
C5: T491A336K004AT; 3216-18
C6: EDK105M050A9BAA
C7, C8: 4.7uF; 0805
CF2: 39pF; 0805
CS1: 1uF; 0805
D2: MBRS140T3-D; MBRS140T3G
D4: 1N5819HW-7-F; SOD123
IC_1: LTC4412; SOT23-6L
IC_3: LP298XS; SOT23-5L
IC_4: LM2621; R-PDSO-G8
IC_6: MCP73831T-2ATI/OT; SOT95P300X145-5N
JP3: BATT; JST-2-PTH-NS
JP5: POWER_JACKPTH; POWER_JACK_PTH
L6, L7: NR4018T6R8M; NR4018/NRS4018
Q9: SI2301CDS; SOT23
R2: 500; 0805
R3, R5: 10k; 0805
R4: 2K; 0805
RF3: 120K; 0805
RF4: 39K; 0805
RFQ1: 60K; 0805
U1: MIC5219 3.3V; SOT23-5

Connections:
1V8: C9.2, IC_3.5 (VOUT)
1V8_EN: IC_3.3 (EN)
3V3: C1.2, R3.2, R5.2, U1.5 (OUT)
5V: C4.1, C7.2, CF2.2, D2.2, IC_3.1 (VIN), IC_6.4 (VDD), RF3.1, U1.1 (IN), U1.3 (EN)
CHG_STAT: IC_6.1 (STAT), R3.1
GND: C1.1, C2.1, C4.2, C5.2, C6.P$2, C7.1, C8.1, C9.1, C10.1, IC_1.2 (GND), IC_1.3 (CTL), IC_3.2 (GND), IC_4.1 (PGND), IC_4.5 (SGND), IC_6.2 (VSS), JP3.1, JP5.GND, JP5.GNDBREAK, L7.P$1, R4.1, RF4.2, U1.2 (GND)
unnamed: C2.2, U1.4 (BP)
unnamed: CS1.1, IC_4.8 (SW), L6.P$2
unnamed: C6.P$1, IC_4.2 (EN), IC_4.6 (VDD), R2.1, RFQ1.2
unnamed: IC_4.3 (FREQ), RFQ1.1
unnamed: CF2.1, IC_4.4 (FB), RF3.2, RF4.1
unnamed: CS1.2, D2.1, L7.P$2
unnamed: IC_6.5 (PROG), R4.2
unnamed: IC_1.5 (GATE), Q9.1 (GATE)
unnamed: C10.2, IC_3.4 (BYP)
PWR_STAT: IC_1.4 (STAT), R5.1
VBATT: C8.2, IC_1.1 (VIN), IC_6.3 (VBAT), JP3.2, Q9.3 (DRAIN)
VEXT: D4.2 (ANODE), JP5.PWR
VIN: C5.1, D4.1 (CATHODE), IC_1.6 (SENSE), IC_4.7 (BOOT), L6.P$1, Q9.2 (SOURCE), R2.2

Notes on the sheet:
INPUTS
OUTPUTS
SIGNAL INPUTS
SIGNAL OUTPUTS

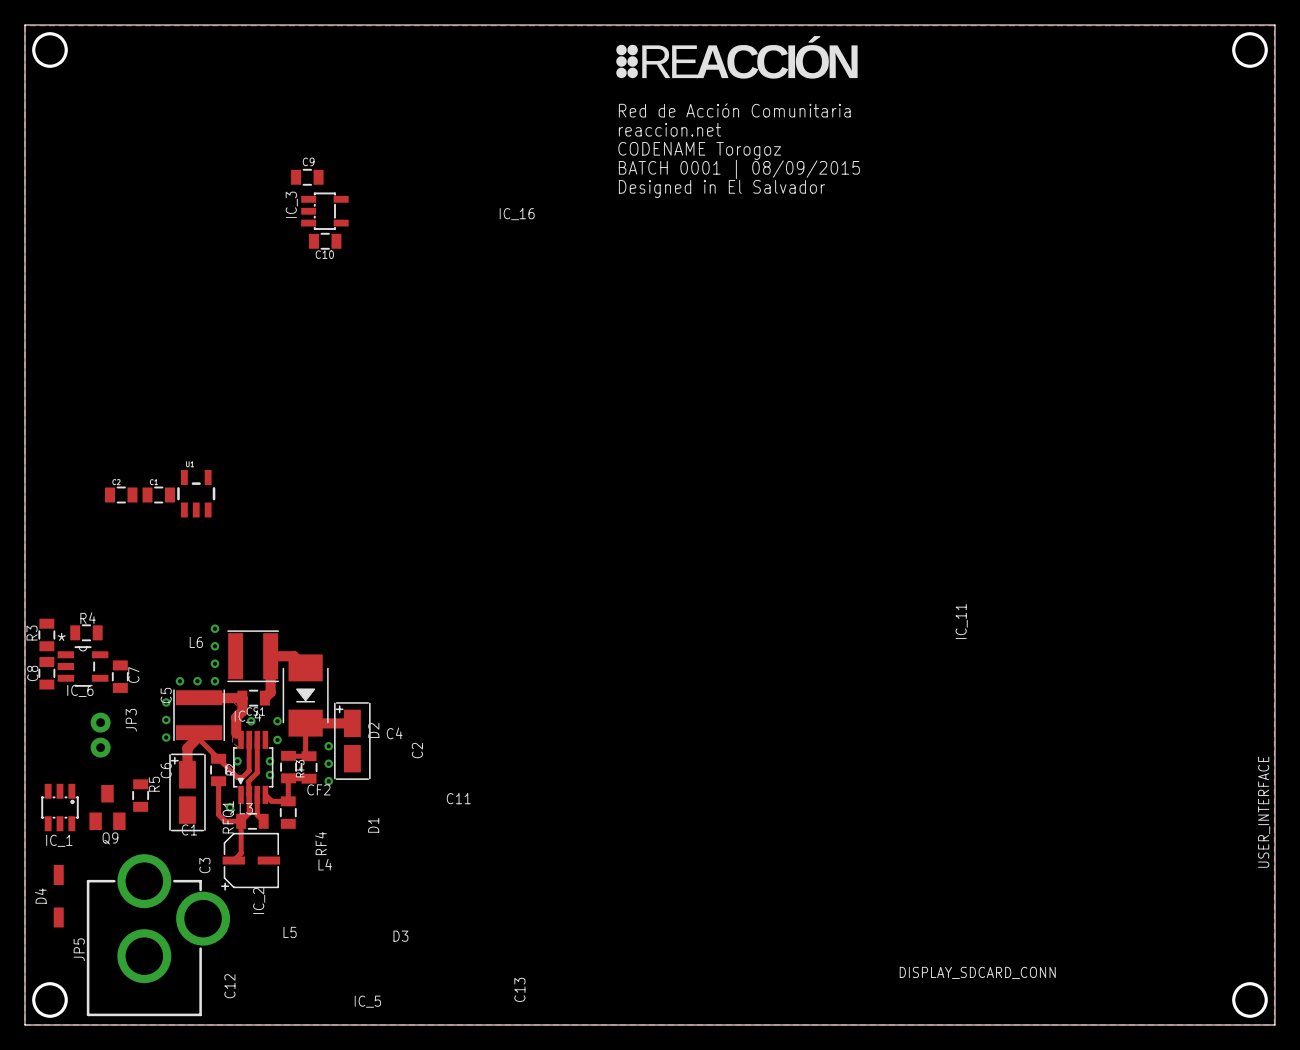
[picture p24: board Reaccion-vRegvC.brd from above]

Board: 2 copper layers, 100.0 x 80.0 mm, 30 parts (0 on the bottom side), 18 nets.

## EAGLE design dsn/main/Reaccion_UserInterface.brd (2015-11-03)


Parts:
C1: 1.0uF; 0805
COLS: M03; JST-3-SMD
JP1: M04PTH; 1X04
ROWS: M03; JST-3-SMD
U1: LCD-16X2SILK; LCD-16X2
U2: ATMEGA328P_PDIP; DIL28-3
U$1: TRIMPOTTC33X; TC33X

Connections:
A: U1.15 (A)
GND: C1.2, JP1.4, U1.1 (VSS), U1.5 (R/W), U2.8 (GND), U2.22 (GND), U$1.1 (A)
K: U1.16 (K)
unnamed: JP1.2, U2.27 (PC4(ADC4/SDA))
unnamed: JP1.3, U2.28 (PC5(ADC5/SCL))
unnamed: U1.7 (DB0), U2.4 (PD2(INT0))
unnamed: U1.8 (DB1), U2.5 (PD3(INT1))
unnamed: U1.9 (DB2), U2.6 (PD4(XCK/T0))
unnamed: U1.10 (DB3), U2.11 (PD5(T1))
unnamed: U1.6 (E), U2.17 (PB3(MOSI/OC2))
unnamed: U1.4 (RS), U2.18 (PB4(MISO))
unnamed: COLS.3, U2.19 (PB5(SCK))
unnamed: U1.3 (VO), U$1.2 (S)
unnamed: COLS.2, U2.16 (PB2(SS/OC1B))
unnamed: COLS.1, U2.15 (PB1(OC1A))
unnamed: ROWS.3, U2.14 (PB0(ICP))
unnamed: ROWS.2, U2.13 (PD7(AIN1))
unnamed: ROWS.1, U2.12 (PD6(AIN0))
VCC: C1.1, JP1.1, U1.2 (VDD), U2.7 (VCC), U2.20 (AVCC), U2.21 (AREF), U$1.3 (E)

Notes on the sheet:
3x3 button Matrix

Board: 2 copper layers, 7 parts (5 on the bottom side), 17 nets, no tracks yet.

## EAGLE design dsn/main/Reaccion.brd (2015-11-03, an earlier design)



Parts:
BAT1: BATTERY12PTH; BATTCON_12MM_PTH
C1, C2, C11: 22pF; 0805
C3, C4, C5, C10, C12: 0.1uF; 0805
C6: 100nF; 0805
C7: 47pF; 0805
C8, C9: 4.7uF; 0603-CAP
C13: 10uF; 1206
D1, D2, D3: DIODESOD; SOD-323
FTDI_CONN: M06SIP; 1X06
GPS_CONN: M06SIP; 1X06
GSM_MODEM: PROPOXGSM900; CONN-13X2
I2C_CONN: M04PTH; 1X04
IC1: DIL8; DIL08
ISP1: AVRISP-6; AVRISP
JP1: USB-MICROB
L1: 4.7uH, 1.2A; CDRH2D09
LIPO_PWR: JST_2MM_MALE; JST-2-SMD
Q1, Q2: BSS101; TO92
R1, R5: 10k; 0805
R2: 100K; 0805
R3, R4: 10K; 0805
R6: 1M; 0805
R7: 2.0k; 0603-RES
R8, R10, R11: 1.2M; 0603-RES
R9: 220k; 0603-RES
R12, R13: 10K; 0603-RES
S1: TAC_SWITCHPTH; TACTILE-PTH
SD_CARD_STORAGE: SD_CARD_SOCKET4UCON; SDCARD_4UCONN
SL1: M02; 02P
U1: MCP73831; SOT23-5
U2: ATMEGA1280V-8AU; QFP50P1600X1600X120-100N
U3: TPS61200; QFN-10_PAD
U4: FT231XS; SSOP20_L
U$2: LIPO-OUTLINE2000; LIPO-2000
XBEE-900HP: XBEE
Y1: CRYSTAL10.5X4.8; CRYSTAL-SMD-10.5X4.8-2PIN

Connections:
CALENDAR_INT: IC1.7, U2.6 ((OC3B/INT4)_PE4)
CHG_STAT: U1.1 (STAT)
D+: JP1.D+, U4.12 (USBDM)
D-: JP1.D-, U4.11 (USBDP)
DOUT,RX: U2.63 ((RXD3/PCINT9)PJ0), XBEE-900HP.2 (DOUT)
EN: R13.1, U3.6 (EN)
FTDI_DTR: C3.1, FTDI_CONN.6, U4.1 (!DTR)
FTDI_POWER: D3.2 (A), FTDI_CONN.3, R5.2, U4.3 (VCCIO), U4.13 (3V3OUT)
FTDI_RXD: FTDI_CONN.5, U2.3 ((TXD0)_PE1), U4.4 (RXD)
FTDI_TXD: FTDI_CONN.4, U2.2 ((RXD0/PCINT8)_PE0), U4.20 (TXD)
GND: BAT1.GND (-), C1.2, C2.2, C4.1, C5.1, C6.2, C7.1, C8.1, C9.1, C10.1, C11.1, C13.2, FTDI_CONN.1, GPS_CONN.6, GSM_MODEM.GND, GSM_MODEM.GND2 (GND), GSM_MODEM.GND3 (GND), GSM_MODEM.GND4 (GND), I2C_CONN.4, IC1.3, IC1.4, ISP1.6 (GND), JP1.GND, JP1.MT1 (GND), JP1.MT2 (GND), LIPO_PWR.1 (-), Q2.1 (S), R5.1, R6.1, R7.1, S1.1, S1.2, SD_CARD_STORAGE.3 (VSS1), SD_CARD_STORAGE.6 (VSS2), SD_CARD_STORAGE.CD, SD_CARD_STORAGE.SH@1 (SH), SD_CARD_STORAGE.SH@2 (SH), SL1.2, U1.2 (VSS), U2.11 (GND), U2.32 (GND_2), U2.62 (GND_2), U2.81 (GND_3), U2.99 (GND), U3.4 (PGND), U3.11 (PAD), U3.12 (PAD), U3.13 (PAD), U3.14 (PAD), U3.15 (PAD), U4.6 (GND), U4.16 (GND), XBEE-900HP.10 (GND), XBEE-900HP.14 (VREF)
GND1: R9.1, R11.1, U3.9 (GND)
GPS_RST: GPS_CONN.3
GPS_RXD: GPS_CONN.1, U2.46 ((TXD1/INT3)_PD3)
GPS_TXD: GPS_CONN.2, U2.45 ((RXD1/INT2)_PD2)
ISP_CLK: SD_CARD_STORAGE.5 (CLK)
ISP_MISO: ISP1.1 (MISO), U2.22 ((MISO/PCINT3)_PB3)
ISP_MOSI: ISP1.4 (MOSI), U2.21 ((MOSI/PCINT2)_PB2)
ISP_RST: ISP1.5 (RST), U2.23 ((OC2A/PCINT4)_PB4)
ISP_SCK: ISP1.3 (SCK), U2.20 ((SCK/PCINT1)_PB1)
MDM_PWR: Q1.2 (G), R2.1, U2.58 (PC5(A13))
MODEM_RXD: GSM_MODEM.RXD, U2.13 ((TXD2)_PH1)
MODEM_STATUS: GSM_MODEM.STATUS
MODEM_TXD: GSM_MODEM.TXD, U2.12 ((RXD2)_PH0)
unnamed: BAT1.VCC@1 (+), D2.2 (A)
unnamed: R7.2, U1.5 (PROG)
unnamed: Q2.3 (D), XBEE-900HP.5 (RESET)
unnamed: GSM_MODEM.PWRKEY_OUT, Q1.3 (D)
unnamed: GSM_MODEM.PWRKEY, Q1.1 (S), R2.2
unnamed: C10.2, U3.1 (VAUX)
unnamed: R8.1, R9.2, U3.10 (FB)
unnamed: L1.P$1 (1), U3.3 (L)
unnamed: C12.1, R10.1, R11.2, U3.7 (UVLO)
PS: R12.1, U3.8 (PS)
RST_LINE: C3.2, R1.1, S1.3, S1.4, U2.30 (!RESET)
SCL: I2C_CONN.2, IC1.6, R4.2, U2.43 ((SCL/INT0)_PD0)
SDA: I2C_CONN.3, IC1.5, R3.2, U2.44 ((SDA/INT1)_PD1)
SPI_MISO: SD_CARD_STORAGE.8 (DAT1)
SPI_MOSI: SD_CARD_STORAGE.2 (CMD)
TX,DIN: U2.64 ((TXD3/PCINT10)PJ1), XBEE-900HP.3 (DIN)
USD_CS: SD_CARD_STORAGE.1 (CD/DAT3), U2.17 ((OC4C)_PH5)
VBUS: C9.2, JP1.VBUS, U1.4 (VIN), U4.15 (VCC)
VCC: C4.2, C5.2, C6.1, C7.2, C11.2, D1.2 (A), D3.1 (C), GPS_CONN.5, I2C_CONN.1, ISP1.2 (VCC), R1.2, R3.1, R4.1, R8.2, SD_CARD_STORAGE.4 (VDD), U2.10 (VCC_2), U2.31 (VCC), U2.61 (VCC_2), U2.80 (VCC), U2.98 (AREF), U2.100 (AVCC), U3.2 (VOUT), XBEE-900HP.1 (VCC)
VRTC: D1.1 (C), D2.1 (C), GSM_MODEM.VRTC, IC1.8
V_BATT: C8.2, C12.2, C13.1, GSM_MODEM.VBAT, GSM_MODEM.VBAT2 (VBAT), GSM_MODEM.VBAT3 (VBAT), L1.P$2 (2), LIPO_PWR.2 (+), R10.2, R12.2, R13.2, SL1.1, U1.3 (VBAT), U3.5 (VIN)
XBEE_CTS: XBEE-900HP.12 (CTS/DIO7)
XBEE_RESET: Q2.2 (G), R6.2, U2.15 ((OC4A)_PH3)
XBEE_RTS: XBEE-900HP.16 (RTS/AD6/DIO6)
XBEE_SLEEP: XBEE-900HP.13 (ON/SLEEP)
XB_SLEEP: U2.59 (PC6(A14))
XTAL1: C2.1, U2.34 (XTAL1), Y1.P$1 (1)
XTAL2: C1.1, U2.33 (XTAL2), Y1.P$2 (2)

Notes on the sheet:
Tableta controladora para el kit reacción v0.1beta Elaborado por Mario Gomez para Reaccion.net Última revisión: 2014-01-21 Liberado bajo licencia Creative Commons CC-BY-SA http://creativecommons.org/licenses/by-sa/2.0/

Board: 2 copper layers, 51 parts (0 on the bottom side), 42 nets, no tracks yet.

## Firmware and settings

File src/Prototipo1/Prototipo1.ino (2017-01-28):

#include <SPI.h>
#include <Wire.h>
#include <SoftwareSerial.h>
#include <EEPROM.h>
//#include <SD.h>
#include <SdFat.h>
#include "pinmap.h"
#include "NMEAGPS_cfg.h"
#include "NMEAGPS.h"
#include "MS5637Barometer.h"
#include "MAX7313.h"
#include "Adafruit_GFX.h"
#include "Adafruit_ILI9340.h"
#include "LibXBee.h"
#include "data_frames.h"
#include "globals.h"
#include "utils.h"
#define MBEDTLS_SHA1_C
#include "sha1.h"
#include "sha1.c"

#define _F(string_literal) (reinterpret_cast<__FlashStringHelper *>(PSTR(string_literal)))

#define FILE_NAME "DATALOG.TXT"

SoftwareSerial Serial4(24, 25);
/* Aliases for serial devices */
#define USB_SER Serial
#define XBEE_SER Serial1
#define GSM_SER Serial2
#define GPS_SER Serial3
#define BT_SER Serial4

NMEAGPS gps;

gps_fix fix_data;

Adafruit_ILI9340 tft = Adafruit_ILI9340(SPI1_CS, DISPLAY_DC, SPI1_RST);
MS5637Barometer baroSensor;
MAX7313 externalIO(0x20, IO_INT0);

mbedtls_sha1_context sha1_context;

uint8_t shared_key[SHARED_KEY_SIZE+1];

uint32_t msgCount = 0;

uint32_t getMsgCount() {
  uint32_t count = 0;
  count = EEPROM.read(EEPROM_MSG_COUNT_OFFSET);
  count |= EEPROM.read(EEPROM_MSG_COUNT_OFFSET+1)<<8;
  count |= EEPROM.read(EEPROM_MSG_COUNT_OFFSET+2)<<16;
  return count;
}

uint32_t incMsgCount() {
  msgCount += 1;
  EEPROM.write(EEPROM_MSG_COUNT_OFFSET, msgCount & 0xFF);
  EEPROM.write(EEPROM_MSG_COUNT_OFFSET, (msgCount>>8) & 0xFF);
  EEPROM.write(EEPROM_MSG_COUNT_OFFSET, (msgCount>>16) & 0xFF);
  return getMsgCount();
}

void setSharedKey(uint8_t *key) {
  for(int i=0;i<SHARED_KEY_SIZE;i++) {
    EEPROM.write(EEPROM_SHARED_KEY_OFFSET+i,key[i]);
  }
}

void getSharedKey(uint8_t *shared) {
  for(int i=0;i<SHARED_KEY_SIZE;i++) {
    shared[i] = EEPROM.read(EEPROM_SHARED_KEY_OFFSET+i);
  }
} 

void setup() {
  /* READ NON-VOLATILE MEMORY */
  // Get Hardware-ID
  MY_ID = getHWId();
  // Get Shared KEY from EEPROM
  getSharedKey(shared_key);
  // Get message count from EEPROM
  msgCount = getMsgCount();
  
  /* SETUP IO PINS */
  // Set up pins for XBee Module
  pinMode(XBEE_RESET, OUTPUT); // XBee reset pin
  digitalWrite(XBEE_RESET, HIGH);
  pinMode(XBEE_SLEEP, OUTPUT); // XBee sleep pin
  digitalWrite(XBEE_SLEEP, HIGH);
  
  /* IO PINS FOR GSM MODULE */
  pinMode(SIM900_PWR, OUTPUT); // Power pin
  digitalWrite(SIM900_PWR, LOW);
  pinMode(SIM900_RESET, OUTPUT); // Reset pin
  digitalWrite(SIM900_RESET, LOW);
  pinMode(SIM900_RI, INPUT); // Ring line
  pinMode(SIM900_STATUS, INPUT); // Status pin

  /* IO PINS FOR GPS MODULE */
  pinMode(GPS_ONOFF, OUTPUT); // GPS start pulse
  digitalWrite(GPS_ONOFF, LOW);
  pinMode(GPS_TM, INPUT); // 1PPS Time mark
  pinMode(GPS_WU, INPUT); // Wake up signal
  pinMode(GPS_RST, OUTPUT);
  digitalWrite(GPS_RST, HIGH); // GPS Reset

  /* IO PINS FOR BLUETOOTH MODULE */
  pinMode(BT_EN, OUTPUT); // Enable power on BT
  digitalWrite(BT_EN, LOW);
  pinMode(BT_CMD, OUTPUT); // Command mode BT
  digitalWrite(BT_EN, LOW);

  /* IO PINS DISPLAY & SD MODULE */
  pinMode(DISPLAY_DC, OUTPUT); // TFT Data/Command
  digitalWrite(DISPLAY_DC, LOW);
  pinMode(DISPLAY_SDCS, OUTPUT); // SD Card Chip select
  digitalWrite(DISPLAY_SDCS, HIGH);
  pinMode(SPI1_CS, OUTPUT); // TFT Chip select
  digitalWrite(SPI1_CS, HIGH);
  pinMode(DISPLAY_BL, OUTPUT); // TFT & buttons backlight
  digitalWrite(DISPLAY_BL, LOW);

  /* OTHER HARDWARE IO PINS */
  pinMode(EN_12V, OUTPUT); // 12V boost converter startup
  digitalWrite(EN_12V, LOW); // Disable on boot.
  pinMode(BUZZER_ACT, OUTPUT); // Buzzer activation
  digitalWrite(BUZZER_ACT, LOW); // Disable on boot.
  pinMode(DISPLAY_BL, OUTPUT); //Backlight control

  /* IO PINS FOR GSM MODULE */
  // TODO: Implement event based user interface
  pinMode(IO_INT0, INPUT_PULLUP); // External interrupt pin
  attachInterrupt(IO_INT0, intIoExpansor, CHANGE);

  /* SETUP LOW LEVEL DEVICES */
  // Enable USB debug serial port
  USB_SER.begin(115200);
  // Enable serial port for XBee Module
  XBEE_SER.begin(9600);
  // Enable serial port for SIM900 Module
  GSM_SER.begin(9600);
  // Enable serial port for GPS
  GPS_SER.begin(4800);

#ifdef DEBUG_REACCION
  USB_SER.println("COM ports started.");
  USB_SER.print("Core ID: ");
  USB_SER.println(MY_ID, HEX);
  USB_SER.print("Network Key: ");
  USB_SER.println(shared_key);
#endif
  // Enable AltSoft serial port for Bluetooth
  BT_SER.begin(38400);

#ifdef DEBUG_REACCION
  USB_SER.println("Software COM port for Bluetooth enabled.");
#endif

  // Enable SPI bus for TFT Display and SD Card
  SPI.setMOSI(SPI1_MOSI);
  SPI.setMISO(SPI1_MISO);
  SPI.setSCK(SPI1_SCK);
  SPI.begin();
  SPI.setClockDivider(SPI_CLOCK_DIV4);

#ifdef DEBUG_REACCION
  USB_SER.println("SPI Port enabled.");
#endif
  // Enable I2C bus for other devices
  Wire.begin();
  
#ifdef DEBUG_REACCION
  USB_SER.println("I2C Port enabled.");
#endif
  /* SETUP HARDWARE-ABSTRACTED DEVICES  */

  /* BEGIN TFT INIT SECTION */
#ifdef DEBUG_REACCION
  USB_SER.println("Starting TFT");
#endif
  // Turn on backlight
  analogWrite(DISPLAY_BL, 255);
#ifdef DEBUG_REACCION
  USB_SER.println("Backlight ON");
#endif
  tftInit();
#ifdef DEBUG_REACCION
  USB_SER.println("TFT started");
#endif

  // Baro/Temp sensor I2C setup
  baroSensor.init();
  baroSensor.setOSR(OSR_2048);
#ifdef DEBUG_REACCION
  USB_SER.println("Barometric sensor started");
#endif

  // Init defaults for MAX7313
  externalIO.init();
  externalIO.digitalWrite(10, 0);
  externalIO.digitalWrite(11, 0);
#ifdef DEBUG_REACCION
  USB_SER.println("External IO enabled");
#endif
  
  /* BEGIN XBEE SECTION */
#ifdef DEBUG_REACCION
  USB_SER.println("Starting XBee radio.");
#endif
  printStatus(("Iniciando Radio..."), ILI9340_YELLOW);
  myXBee = new XBee900HP(&Serial1);
  myXBee->onFrameReceived(xBeeFrameReceived);
  myXBee->init(); // Blocks execution until the Xbee has been correctly initialized
  printStatus(("Radio iniciado."), ILI9340_GREEN);
#ifdef DEBUG_REACCION
  USB_SER.println("Radio succesfully started");
#endif
  /* END XBEE SECTION */
  delay(100); // Delay needed to see messages
  /* BEGIN GPS INIT SECTION*/
#ifdef DEBUG_REACCION
  USB_SER.println("Starting GPS");
#endif
  printStatus(("Iniciando GPS..."), ILI9340_YELLOW);
  initGPS();
  printStatus(("GPS Iniciado."), ILI9340_GREEN);
#ifdef DEBUG_REACCION
  USB_SER.println("GPS Started");
#endif
  /* END GPS INIT SECTION */
  delay(100); // Delay needed to see messages
  /* BEGIN FLASHCARD INIT */
  //const uint8_t BASE_NAME_SIZE = sizeof(FILE_BASE_NAME) - 1;
  //char fileName[13] = FILE_BASE_NAME "00.csv";
#ifdef DEBUG_REACCION
  USB_SER.println("Trying to access SD Card");
#endif
  if (!sd.begin(DISPLAY_SDCS, SPI_HALF_SPEED)) {
    printStatus(("Error Iniciando SD"), ILI9340_RED);
#ifdef DEBUG_REACCION
  USB_SER.println("Error on SD Card init");
#endif
  }
  /*
  while (sd.exists(fileName)) {
    if (fileName[BASE_NAME_SIZE + 1] != '9') {
      fileName[BASE_NAME_SIZE + 1]++;
    } else if (fileName[BASE_NAME_SIZE] != '9') {
      fileName[BASE_NAME_SIZE + 1] = '0';
      fileName[BASE_NAME_SIZE]++;
    } else {
      printStatus(("CNNOTCREAT"));
    }
  }*/
  delay(100);
#ifdef DEBUG_REACCION
  USB_SER.println("Creating file in SD");
#endif
  if (!file.open(FILE_NAME, O_CREAT | O_WRITE)) {
    printStatus(("Error Iniciando FS"), ILI9340_RED);
#ifdef DEBUG_REACCION
  USB_SER.println("Error creating file");
#endif
  } else {
#ifdef DEBUG_REACCION
  USB_SER.println("SD Memory ready");
#endif
    printStatus(("MEM LISTA"), ILI9340_GREEN);
    file.println(("Starting up..."));
    file.sync();
    file_ready = true;
  }
  /* END FLASHCARD INIT */

  /* BEGIN INIT UI globals */
  timeoutA = millis();
  /* END INIT UI globals */
#ifdef DEBUG_REACCION
  USB_SER.println("[[REACCION READY]]");
#endif
  printStatus(("REACCION listo."), ILI9340_GREEN);
  delay(100);

  // Init SHA-1
  mbedtls_sha1_init(&sha1_context);
}

void intIoExpansor() {
  // ISR for changes on IO Expansor board.
}

void selfMonitor() {
  tft.fillRect(250,0, 320, 20, ILI9340_BLACK);
  tft.setCursor(250,0);
  /* Not implemented on this board revision
  switch(externalIO.digitalRead(CHG_STAT)) {
    case 0:
      tft.print('-');
      break;
    case 1:
      tft.print('C');
      break;
  }
  switch(externalIO.digitalRead(PWR_STAT)) {
    case 0:
      tft.print('-');
      break;
    case 1:
      tft.print('P');
      break;
  } */
  switch(gps.fix().valid.location) {
    case 0:
      tft.setTextColor(ILI9340_RED);
      break;
    case 1:
      tft.setTextColor(ILI9340_GREEN);
      break;
  }
  tft.print('G');
  tft.setTextColor(ILI9340_WHITE);
  int battVoltage = analogRead(A10);
  float fVoltage = (3.3/1024)*battVoltage*2;
  tft.print(fVoltage);
}

int currTest = 0;

void printWait(int seconds) {
  for(int i=0;i<seconds;i++) {
#ifdef DEBUG_REACCION
    USB_SER.print(seconds-i,DEC);
    USB_SER.print("\n");
#endif
    delay(1000);
  }
}

void sim900powerON() {
  digitalWrite(SIM900_PWR,HIGH);
  delay(1500);
  digitalWrite(SIM900_PWR,LOW);
  delay(3000);
}

void sim900powerOFF() {
  digitalWrite(SIM900_PWR,HIGH);
  delay(2500);
  digitalWrite(SIM900_PWR,LOW);
  delay(3000);
}

void controlBackLight() {
  if((millis()-blTimeout)<MAX_BL || buzzer_enabled == true) {
    externalIO.digitalWrite(10, 0);
    externalIO.digitalWrite(11, 0);
    analogWrite(DISPLAY_BL, 255);
  } else {
    externalIO.digitalWrite(10, 1);
    externalIO.digitalWrite(11, 1);
    analogWrite(DISPLAY_BL, 0);
  }
}

struct Message {
  uint32_t origin = -1;
  int level = -1;
  long lastMessage = 0;
  uint32_t lat = 0;
  uint32_t lon = 0;
};

struct Message lastMessages[4];

void pushQueue(struct Message msg) {
  lastMessages[3].origin = lastMessages[2].origin;
  lastMessages[3].level = lastMessages[2].level;
  lastMessages[3].lastMessage = lastMessages[2].lastMessage;
  lastMessages[3].lat = lastMessages[2].lat;
  lastMessages[3].lon = lastMessages[2].lon;
  lastMessages[2].origin = lastMessages[1].origin;
  lastMessages[2].level = lastMessages[1].level;
  lastMessages[2].lastMessage = lastMessages[1].lastMessage;
  lastMessages[2].lat = lastMessages[1].lat;
  lastMessages[2].lon = lastMessages[1].lon;
  lastMessages[1].origin = msg.origin;
  lastMessages[1].level = msg.level;
  lastMessages[1].lastMessage = msg.lastMessage;
  lastMessages[1].lat = msg.lat;
  lastMessages[1].lon = msg.lon;
}

void drawQueue() {
  tft.fillRect(0,100, 320, 140, ILI9340_BLACK);
  tft.setTextSize(2);
  tft.setCursor(0, 100);
  drawMsg(1,1);
  drawMsg(2,1);
  drawMsg(3,1);
}

void drawMsg(int idx, int fmt) {
  switch(lastMessages[idx].level) {
    case 1:
      tft.setTextColor(ILI9340_GREEN);
      tft.print((" K"));
      tft.print(getHumanId(lastMessages[idx].origin));
      tft.print((": "));
      tft.print(("[Verde] ("));
      break;
    case 2:
      tft.setTextColor(ILI9340_YELLOW);
      tft.print((" K"));
      tft.print(getHumanId(lastMessages[idx].origin));
      tft.print((": "));
      tft.print(("[Amarillo] ("));
      break;
    case 3:
      tft.setTextColor(ILI9340_RED);
      tft.print((" K"));
      tft.print(getHumanId(lastMessages[idx].origin));
      tft.print((": "));
      tft.print(("[Rojo] ("));
      break;
    case 4:
      tft.setTextColor(ILI9340_WHITE);
      tft.print((" K"));
      tft.print(getHumanId(lastMessages[idx].origin));
      tft.print((": "));
      tft.print(("[Blanco] ("));
      break;
    default:
      tft.setTextColor(ILI9340_WHITE);
      tft.println(("  [Sin estado]"));
      break;
  }
  if(lastMessages[idx].level>=1 && lastMessages[idx].level<=4) {
      tft.print((millis()-lastMessages[idx].lastMessage)/60000, DEC);
      tft.println((" min)"));
      tft.print((" "));
      switch(fmt) {
        case 0:
          tft.print((millis()-lastMessages[idx].lat)/100000);
          tft.print(("N -"));
          tft.print((millis()-lastMessages[idx].lat)/100000);
          tft.println(("W"));
          break;
        case 1:
          tft.print(("@ "));
          tft.print(distance(gps.fix().lat,gps.fix().lon,lastMessages[idx].lat,lastMessages[idx].lon),DEC);
          tft.println("m");
          break;
      }
  }
}

void drawLastStatus() {
  tft.fillRect(0,40, 320, 40, ILI9340_BLACK);
  tft.setTextSize(2);
  tft.setCursor(0, 40);
  drawMsg(0,0);
}

long lastUpdate = 0;

void loop() {
  myXBee->listen();
  controlBackLight();
  
  if((millis()-lastUpdate)>10000) {
    drawLastStatus();
    drawQueue();
    selfMonitor();
    lastUpdate = millis();
  }
  // Monitor inputs
  if(
      externalIO.digitalRead(BTN_A)==LOW ||
      externalIO.digitalRead(BTN_B)==LOW ||
      externalIO.digitalRead(BTN_C)==LOW ||
      externalIO.digitalRead(BTN_D)==LOW) {
    tft.setCursor(75, 224);
    if(externalIO.digitalRead(BTN_A)==LOW) {
      tft.fillRect(0,220, 320, 20, ILI9340_GREEN);
      tft.setTextColor(ILI9340_BLACK);
    } else if(externalIO.digitalRead(BTN_B)==LOW) {
      tft.fillRect(0,220, 320, 20, ILI9340_YELLOW);
      tft.setTextColor(ILI9340_BLACK);
    } else if(externalIO.digitalRead(BTN_C)==LOW) {
      tft.fillRect(0,220, 320, 20, ILI9340_RED);
      tft.setTextColor(ILI9340_WHITE);
    } else if(externalIO.digitalRead(BTN_D)==LOW) {
      tft.fillRect(0,220, 320, 20, ILI9340_WHITE);
      tft.setTextColor(ILI9340_BLACK);
    }
    tft.print(("[Enviando en "));
    tft.print((5000-(millis()-timeoutA))/1000, DEC);
    tft.print(("]"));
    //USB_SERIAL.println("Button down");
    blTimeout = millis();
    if(olderThan(timeoutA,BTN_TIMEOUT)) {
#ifdef DEBUG_REACCION
      USB_SERIAL.println("Sending message");
#endif
      if(externalIO.digitalRead(BTN_A)==LOW) {
        broadcastAlert(0,0x01);
      } else if (externalIO.digitalRead(BTN_B)==LOW){
        broadcastAlert(0,0x02);
      } else if (externalIO.digitalRead(BTN_C)==LOW) {
        broadcastAlert(0,0x03);
      } else if (externalIO.digitalRead(BTN_D)==LOW) {
        broadcastAlert(0,0x04);
      }
      timeoutA = millis();
    }
    if(buzzer_enabled) {
      digitalWrite(BUZZER_ACT, LOW);
      delay(100);
      digitalWrite(EN_12V, LOW); // Disable 12V power source
      buzzer_enabled = false;
    }
  } else {
    tft.fillRect(0,220, 320, 20, ILI9340_BLACK);
    timeoutA = millis();
  }

  if(GPS_SER.available()) {
    uint8_t c = GPS_SER.read();
    gps.decode(c);
    if(gps.fix().valid.location) {

#ifdef DEBUG_REACCION
      USB_SERIAL.println("GPS Fixed");
#endif
      /*
      tft.fillRect(0,290, 40, 50, ILI9340_RED);
      tft.setTextColor(ILI9340_WHITE);
      tft.setTextSize(2);
      tft.setCursor(0, 200);
      tft.print(("Te encuentras a \n"));
      tft.print(distance(gps.fix().lat,gps.fix().lon,139277359,-898317289),DEC);
      tft.print(("m de Getsemani"));
      */
    }
  }
  // Clear status message if older than X seconds
  if(olderThan(lastStatus,5000)) {
    tft.fillRect(0,200, 320, 40, ILI9340_BLACK);
  }
}

void initGPS() {
  GPS_SER.setTimeout(10000);
  if(GPS_SER.find("GPGGA")) {
#ifdef DEBUG_REACCION
    USB_SERIAL.println("GPS Data found");
#endif
  } else {
#ifdef DEBUG_REACCION
    USB_SERIAL.println("NF _Trying to start GPS Unit");
#endif
    digitalWrite(GPS_ONOFF,HIGH);
    delay(500);
    digitalWrite(GPS_ONOFF,LOW);
  }
}

void tftInit() {
  tft.begin();
  tft.setRotation(1);
  tft.fillScreen(ILI9340_BLACK);
  tft.setCursor(0, 0);
  tft.setTextColor(ILI9340_RED);
  tft.setTextSize(2);
  tft.print(("REACCION KIT-"));
  tft.print(getHumanId(MY_ID), DEC);
  tft.setCursor(0, 20);
  tft.setTextColor(ILI9340_WHITE);
  tft.setTextSize(2);
  tft.println(("Tu estado:"));
  drawLastStatus();
  tft.setCursor(0, 80);
  tft.println(("Mensajes recientes:"));
  drawQueue();
}

void appendUINT8(int8_t v) {
  memcpy(xBeeData+xBeeBuffPos,&v,sizeof(v));
  xBeeBuffPos += sizeof(v);
}

void appendUINT16(uint16_t v) {
  memcpy(xBeeData+xBeeBuffPos,&v,sizeof(v));
  xBeeBuffPos += sizeof(v);
}

void appendUINT32(int32_t v) {
  memcpy(xBeeData+xBeeBuffPos,&v,sizeof(v));
  xBeeBuffPos += sizeof(v);
}

void broadcastAlert(uint8_t category,uint8_t level) {
  clearData();
#if PROTOCOL == PROTOCOL_0
  appendUINT16(PROTOCOL_0); // Protocol version
  appendUINT8(category); // Send Category CAT 00 = TEST
  appendUINT8(level); // Send Message
  appendUINT32(gps.fix().lon); // Send Longitude
  appendUINT32(gps.fix().lat); // Send Latitude
  appendUINT8(gps.fix().dateTime.month);
  appendUINT8(gps.fix().dateTime.date);
  appendUINT8(gps.fix().dateTime.hours);
  appendUINT8(gps.fix().dateTime.minutes);
  appendUINT8(gps.fix().dateTime.seconds);
  myXBee->sendTo64RAW(0x00000000,0x0000FFFF,xBeeData,xBeeBuffPos);
#ifdef DEBUG_REACCION
  USB_SERIAL.println("Sending message");
#endif
#endif
#if PROTOCOL == PROTOCOL_1
/*
typedef struct rx_frame_protocol_1{
  uint16_t version = 1;
  uint32_t origin;
  uint8_t category;
  uint8_t level;
  uint32_t lon;
  uint32_t lat;
  uint8_t month;
  uint8_t date;
  uint8_t hours;
  uint8_t minutes;
  uint8_t seconds;
  int32_t temp;
  int32_t pressure;
  uint32_t running;
};
 */
  rx_frame_protocol_1 tx_data;
  tx_data.origin = MY_ID;
  tx_data.category = 0x00;
  tx_data.level = level;
  tx_data.lon = gps.fix().lon;
  tx_data.lat = gps.fix().lat;
  tx_data.month = gps.fix().dateTime.month;
  tx_data.date = gps.fix().dateTime.date;
  tx_data.hours = gps.fix().dateTime.hours;
  tx_data.minutes = gps.fix().dateTime.minutes;
  tx_data.seconds = gps.fix().dateTime.seconds;
  tx_data.temp = baroSensor.readTemperature();
  tx_data.pressure = baroSensor.readTCPressure();
  tx_data.running = msgCount;
  Serial.println(sizeof(uint16_t),DEC);
  Serial.println(sizeof(tx_data),DEC);
  incMsgCount(); // Incrementar conteo de mensajes
#ifdef DEBUG_REACCION
  USB_SERIAL.print("Message lenght: ");
  USB_SERIAL.println(sizeof(tx_data),DEC);
#endif

  memcpy(xBeeData,&tx_data,sizeof(tx_data));
  mbedtls_sha1_starts(&sha1_context);
  mbedtls_sha1_update(&sha1_context,(uint8_t*)&tx_data,sizeof(tx_data));
  mbedtls_sha1_update(&sha1_context,(uint8_t*)&shared_key,sizeof(SHARED_KEY_SIZE));
  mbedtls_sha1_finish(&sha1_context,xBeeData+sizeof(tx_data));
  mbedtls_sha1_free(&sha1_context);
  myXBee->sendTo64RAW(0x00000000,0x0000FFFF,xBeeData,sizeof(tx_data)+20);
#endif
  
  lastMessages[0].level = level;
  lastMessages[0].origin = getHumanId(MY_ID);
  lastMessages[0].lon = gps.fix().lon;
  lastMessages[0].lat = gps.fix().lat;
  lastMessages[0].lastMessage = millis();
  drawLastStatus();
}


void printStatus(const char *msg, uint8_t txtColor) {
  tft.fillRect(0,200, 320, 40, txtColor);
  tft.setCursor(0,200);
  tft.setTextSize(2);
  tft.print(msg);
  lastStatus = millis();
}

void clearData() {
  for(int i=0;i<XBEE_BUFFER;i++) {
    xBeeData[i] = 0;
  }
  xBeeBuffPos = 0;
}

int32_t extractINT16(uint8_t *start) {
  return *(uint16_t*)(start);
}

int32_t extractINT32(uint8_t *start) {
  return *(uint32_t*)(start);
}

uint8_t equalSHA1(uint8_t a[20], uint8_t b[20]) {
  uint8_t valid = 1;
  for(int i=0;i<20;i++) {
    if(!(valid &= (a[i]==b[i])))
      break;
  }
  return valid;
}
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

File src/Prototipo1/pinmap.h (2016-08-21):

/* BEGIN SIM900 PIN SETUP */
#define SIM900_PWR        2
#define SIM900_RESET      23
#define SIM900_RI         30
#define SIM900_STATUS     31
/* BEGIN GPS PIN SETUP */
#define GPS_ONOFF         14
#define GPS_TM            15
#define GPS_WU            16
#define GPS_RST           17
/* BEGIN XBEE PIN SETUP */
#define XBEE_RESET        28
#define XBEE_SLEEP        22
/* BEGIN BLUETOOTH PIN SETUP */
#define BT_EN             27
#define BT_CMD            33
/* BEGIN SCREEN & SD CARD READER PIN SETUP */
#define DISPLAY_DC        4
#define DISPLAY_SDCS      5
#define SPI1_CS           6
#define SPI1_MISO         11
#define SPI1_MOSI         12
#define SPI1_SCK          13
#define DISPLAY_BL        20
#define SPI1_RST          3
/* BEGIN OTHER IO PIN SETUP */
#define EN_12V            26
#define BUZZER_ACT        23
#define CHG_STAT          1
#define PWR_STAT          0
/* EXTERNAL INTERRUPTS */
#define IO_INT0           32
#define BTN_A             9
#define BTN_B             8
#define BTN_C             6
#define BTN_D             7
#define BTN_E             10
#define BTN_F             11

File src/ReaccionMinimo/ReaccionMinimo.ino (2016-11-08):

/*************************************************************
Reaccion Minimo.
Copyright (C) 2016  Mario Gomez/mxgxw < mario.gomez _at- teubi.co >

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
You should have received a copy of the GNU General Public License
along with this program; if not, write to the Free Software
Foundation, Inc., 51 Franklin Street, Fifth Floor, Boston,
MA  02110-1301, USA.
**************************************************************/
#include <RH_ASK.h>
#include <Adafruit_NeoPixel.h>
#ifdef __AVR__
  #include <avr/power.h>
#endif
#include <LiquidCrystal.h>
#include <SPI.h> // Not actually used but needed to compile
#include <EEPROM.h>
#include "Reaccion.h"
#include "dataframes.h"

#define DEBUG // Comment out to prevent debug messages on serial
/********************** BEGIN NET CONFIG **************************/
#define MAX_HOPS 15
/************************ END NEt CONFIG **************************/
/********************** BEGIN IO MAPPING **************************/
// LCD screen IO mapping
#define LCD_RS 8
#define LCD_E  9
#define LCD_D4 2
#define LCD_D5 3
#define LCD_D6 4
#define LCD_D7 6
#define LCD_BL 10 // Pin 10 supports PWM on Atmega328p
// IO Buttons
#define BTN_1 A0
#define BTN_2 A1
#define BTN_3 A2
#define BTN_4 A3
// RF IO
#define RF_RX 11
#define RF_TX 12
#define RF_PTT 0
// Buzzer
#define BUZZER 7
// Battery level
#define BATT_LVL A7
// User interface
#define HEARTBEAT 5
/************************ END IO MAPPING **************************/
/************************ BEGIN GLOBALS ***************************/
PROGRAM_STATE state = BOOT;
uint8_t node_id = 0;
packet_header last_msg_header;
data_frame_v0 last_msg_data;
data_frame_v0 out_data_frame;
uint8_t rcv_buf[RH_ASK_MAX_MESSAGE_LEN];
uint8_t rcv_buf_len = sizeof(rcv_buf);

/************************** END GLOBALS ***************************/
/************************ BEGIN DRIVERS ***************************/
// Basic network conectivity
RH_ASK driver(2000, RF_RX, RF_TX, RF_PTT, false);
// Pheripherals
LiquidCrystal lcd(LCD_RS, LCD_E, LCD_D4, LCD_D5, LCD_D6, LCD_D7);
Button btn1(BTN_1);
Button btn2(BTN_2);
Button btn3(BTN_3);
Button btn4(BTN_4);
// Helpers
Interval interval5s(2000);
MicroMesh mesh(&driver, rcv_buf, rcv_buf_len, EEPROM_BASE_ADDR+sizeof(node_id));
Adafruit_NeoPixel pixels = Adafruit_NeoPixel(1, HEARTBEAT, NEO_RGB + NEO_KHZ800);
Heartbeat heart(&pixels);
/************************** END DRIVERS ***************************/

/************************** BEGIN CODE  ***************************/
void setup()
{
    pinMode(13, INPUT);
    pinMode(LCD_BL, OUTPUT);
    pinMode(BUZZER, OUTPUT);
    
    // Associate button events
    btn1.onRelease(onRelease);
    btn2.onRelease(onRelease);
    btn3.onRelease(onRelease);
    btn4.onRelease(onRelease);

    btn1.onPush(onPush);
    btn2.onPush(onPush);
    btn3.onPush(onPush);
    btn4.onPush(onPush);

    // Init Neopixel
    

    // Associate interval event
    interval5s.onFinish(onFinish5s);

#ifdef DEBUG
    // Init comm ports.
    Serial.begin(9600);	  // For debug only
#endif

    // New package handler
    EEPROM.get(EEPROM_BASE_ADDR, node_id);
    mesh.onPackage(onPackage);
    
    if (!driver.init())
#ifdef DEBUG
         Serial.println("init failed");
#endif

    // Init user interface
    digitalWrite(LCD_BL, HIGH);
    lcd.begin(16, 2); // User interface
    printBootMsg();
    
#ifdef DEBUG
    Serial.println("Boot message");
#endif
    if(node_id==0 || node_id>15) {
      state = CONF_ID;
      node_id=1;
      printNodeID();
    } else {
      state = BOOT;
      interval5s.start();
    }
    tone(BUZZER, 2000, 500);
}

/************************** LCD Draw Helpers ************************/
void printBootMsg() {
  lcd.setCursor(0, 0);
  lcd.print("Reaccion Minimo");
  lcd.setCursor(0,1);
  lcd.print("Iniciando...");
}

void printWaitMsg() {
  lcd.clear();
  lcd.setCursor(0, 0);
  lcd.print("Esperando");
  lcd.setCursor(0, 1);
  lcd.print("Mensajes");
}

void printNodeID() {
  lcd.clear();
  lcd.setCursor(0,0);
  lcd.print("ID de nodo:");
  lcd.setCursor(0, 1);
  lcd.print(node_id, DEC);
}

void printGreen() {
  lcd.clear();
  lcd.setCursor(0,0);
  lcd.print("VERDE");
  lcd.setCursor(0,1);
  lcd.print("Envia en ");
}

void printYellow() {
  lcd.clear();
  lcd.setCursor(0,0);
  lcd.print("AMARILLO");
  lcd.setCursor(0,1);
  lcd.print("Envia en ");
}

void printWhite() {
  lcd.clear();
  lcd.setCursor(0,0);
  lcd.print("BLANCO");
  lcd.setCursor(0,1);
  lcd.print("Envia en ");
}

void printRed() {
  lcd.clear();
  lcd.setCursor(0,0);
  lcd.print("ROJO");
  lcd.setCursor(0,1);
  lcd.print("Envia en ");
}

void printSentMsg() {
  lcd.clear();
  lcd.setCursor(0,0);
  lcd.print("Mensaje");
  lcd.setCursor(0,1);
  lcd.print("enviado.");
}

void printSeconds() {
  lcd.setCursor(9,1);
  lcd.print(interval5s.secondsRemaining(), DEC);
}

void printMsg() {
  lcd.clear();
  lcd.setCursor(0,0);
  lcd.print("Mensaje de ");
  lcd.setCursor(11,0);
  lcd.print(last_msg_header.origin, DEC);
  lcd.setCursor(0,1);
  switch(last_msg_data.alert_lvl) {
    case 0:
      heart.setColor(0,0,50);
      lcd.print("BLANCO");
      break;
    case 1:
      heart.setColor(50,0,0);
      lcd.print("VERDE");
      break;
    case 2:
      heart.setColor(50,50,0);
      lcd.print("AMARILLO");
      break;
    case 3:
      heart.setColor(0,50,0);
      lcd.print("ROJO");
      break;
  }
}
/***************** Event Handlers for the State Machine **************/
void onPackage(uint8_t *data, uint8_t len) {
  Serial.println("Package received");
  memcpy(&last_msg_header, data, sizeof(packet_header));

  if((len-sizeof(packet_header)) != sizeof(data_frame_v0))
    return; // Invalid payload

  memcpy(&last_msg_data, data+sizeof(packet_header), sizeof(data_frame_v0));

  switch(state) {
    case BOOT:
      break;
    case MSG_RECEIVED:
    case WAIT:
    case PRE_MSG_1:
    case PRE_MSG_2:
    case PRE_MSG_3:
    case PRE_MSG_4:
      interval5s.cancel();
      state = MSG_RECEIVED;
      printMsg();
      tone(BUZZER, 2000);
      break;
  }
}
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

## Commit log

2015-11-03 local init for testing
    [BOM_REACCION.xlsx, BOM_REACCION_FINAL.xlsx, BOM_REACCION_FINAL}.xlsx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]
2015-11-09 PCB re-design
    [Reaccion-v0.9.brd, Reaccion-v0.9.sch, Reaccion-vRegvC.brd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]
2015-11-09 Laen's DRC corrections, small modifications
    [Reaccion-v0.9.brd, Reaccion-v0.9.sch]
2015-11-17 Added power source corrections
    [Reaccion-v0.9.brd, Reaccion-v0.9.sch, ui_connector.brd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]
2015-12-26 Initial release for Prototipo1
    [Reaccion-v0.9.brd, Reaccion-v0.9.csv, Reaccion-v0.9.sch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]
2016-09-07 Reaccion-Minimo.sch for edu purposes finished.
    [Reaccion-Minimo.brd, Reaccion-Minimo.sch]
2016-09-11 Reaccion Minimo UI finished. RX send tested.
    [Reaccion-Minimo.brd, Reaccion-Minimo.sch]
2016-11-08 Added Reaccion-Minimo PASTO
    [Reaccion-Minimo-BOM.csv, Reaccion-Minimo.brd, Reaccion-Minimo.sch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]

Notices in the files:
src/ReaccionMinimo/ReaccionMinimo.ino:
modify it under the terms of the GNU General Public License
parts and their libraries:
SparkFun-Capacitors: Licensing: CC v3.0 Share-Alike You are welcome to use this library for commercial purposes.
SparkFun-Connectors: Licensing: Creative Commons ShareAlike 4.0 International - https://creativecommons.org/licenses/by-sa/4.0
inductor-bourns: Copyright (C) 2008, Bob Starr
